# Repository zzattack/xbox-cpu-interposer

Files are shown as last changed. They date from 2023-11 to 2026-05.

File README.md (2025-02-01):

# Repository overview
In this repository schematics, layout and gerber files are shared for the recreation of an interposer PCB allowing upgraded Intel CPUs to be used on the original Xbox console. The designs are made in KiCAD.

# Background
Back in 2003 the Taiwanese company FRIENDTECH came up with methods to upgrade computer systems with faster CPUs, and the original Xbox was among the devices for which they offered an upgrade path. Details of their solution can be found in their patent application https://patents.google.com/patent/US20050282621A1/en.

This _interposer board_ follows the same schematic, minus the poorly functioning clock reduction circuitry, and with the BGA footprint positioned to allow use of the original heatsink mounting holes.

# Contact
I can be contacted at frank@zzattack.org if you're looking to obtain PCBs or CPUs.

# Attribution
This board is a recreation of the original FRIENDTECH design. Revision 1 was a board-level clone of original design through intermediate clones by 'trusty', 'N64freak' and 'Kekule'. Revisions 2 and 3 are re-routed from scratch, inspired by pictures of a similar board with cleaner layout by @gaasedelen, who also kindly assisted in finding issues with early board revisions.

# Installation guide
See [guide](https://github.com/zzattack/xbox-cpu-interposer/blob/main/guide.md).

# Status
Full schematic and PCB are routed. Gerber files are available in the Github releases overview.
Revision 3.2 and onwards should be working correctly.
Prior revisions require PCB modifications and should be avoided.

rev33
rev33_front
rev33_back

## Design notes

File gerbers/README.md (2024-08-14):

# Ordering information

PCB specifications:
 * 6 layer, 49.5x48.6mm
 * Board thickness: 1.6mm
 * Min track size: 5 mil
 * Min clearance: 5 mil
 * Min drill/via size: 0.3mm / 0.4mm
 * Board-to-edge clearance: 0.2mm
 
These specifications can be used to take advantage of the JLCPCB promotional $2 offer for 5 pieces of 6-layer boards.

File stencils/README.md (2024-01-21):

Order as 0.2mm thick stainless steel.



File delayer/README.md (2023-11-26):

# Delayered scans
This folder contains neatly aligned scans of a delayered 'N64freak' interposer.
They were delayered using sanding paper and scanned with a Canon 9000F flatbed scanner.

It is assumed that the 'trusty', 'N64freak' and 'Kekule' clone boards were recreated from similar scans of an original FRIENDTECH board.

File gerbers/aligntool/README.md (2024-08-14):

# Ordering information

PCB specifications:
 * 2 layer, 49.5x48.6mm
 * Board thickness: 1.0mm
 * No specific tight requirements.

This board can be used to accurately determine the position for mounting the actual interposer.
aligntool

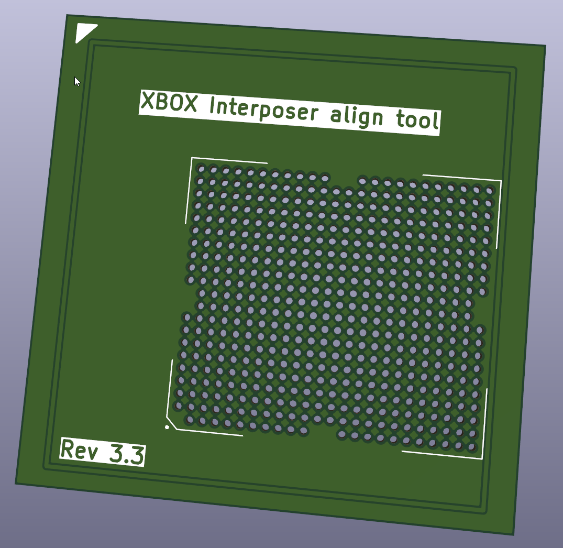
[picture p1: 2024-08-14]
gerbers/aligntool/aligntool.png

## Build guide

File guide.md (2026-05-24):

# XBOX CPU upgrade guide
Applying CPU upgrades to the original Xbox has been done since 2004. Yet, up until recently, resources and information to carry out this procedure have been hard to come by.
This guide aims to gather relevant information, tips and tricks in one place to serve as a reference guide for performing this procedure properly, successfully, and repeatably.
Ideally, even newcomers should succeed on their first try.

Table of Contents
=================
- [XBOX CPU upgrade guide](#xbox-cpu-upgrade-guide)
- [Table of Contents](#table-of-contents)
- [Tools and parts](#tools-and-parts)
- [Motherboard preparations](#motherboard-preparations)
  - [Removal from case](#removal-from-case)
  - [Heatsink removal](#heatsink-removal)
    - [Heatsink bracket removal](#heatsink-bracket-removal)
  - [Thermal paste cleaning](#thermal-paste-cleaning)
  - [Ultrasonic cleaning considerations](#ultrasonic-cleaning-considerations)
  - [Baking](#baking)
- [CPU removal](#cpu-removal)
  - [GPU heat shielding](#gpu-heat-shielding)
  - [CPU lift](#cpu-lift)
    - [Board support](#board-support)
    - [Profile](#profile)
    - [Cooling](#cooling)
- [Interposer mounting](#interposer-mounting)
  - [BGA pads cleaning](#bga-pads-cleaning)
  - [Tenting vias in BGA area](#tenting-vias-in-bga-area)
    - [Why tent the vias?](#why-tent-the-vias)
  - [Positioning the aligntool PCB](#positioning-the-aligntool-pcb)
  - [Interposer preparation](#interposer-preparation)
  - [Soldering the interposer](#soldering-the-interposer)
    - [BGA profile](#bga-profile)
  - [Intermediate checks](#intermediate-checks)
  - [Populating the interposer](#populating-the-interposer)
- [Soldering the CPU](#soldering-the-cpu)
  - [BGA profile](#bga-profile-1)
  - [Testing](#testing)
    - [Troubleshooting](#troubleshooting)
  - [Setting CPU VCORE](#setting-cpu-vcore)
- [CPU/GPU heatsink bracket](#cpugpu-heatsink-bracket)
  - [Capacitor relocation on rev 1.6 motherboard](#capacitor-relocation-on-rev-16-motherboard)
  - [Alternative heatsink mounting solutions](#alternative-heatsink-mounting-solutions)
    - [Thermal glue/adhesive](#thermal-glueadhesive)
    - [Screw mounting posts](#screw-mounting-posts)
  - [Fan recommendation](#fan-recommendation)

<!-- Created by https://github.com/ekalinin/github-markdown-toc -->

# Tools and parts
The most interesting CPUs to place on an original XBOX are part of the Pentium 3 Tualatin family. They have a different PGA-370 footprint compared to the uPGA-495 which is used on the board by default.
We therefore install an adapter in between the board and our intended CPU.

The following parts are needed:
 - [interposer PCB](https://github.com/zzattack/xbox-cpu-interposer/releases/)
 - [components to populate interposer PCB](https://htmlpreview.github.io/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)
 - [aligntool PCB](https://github.com/zzattack/xbox-cpu-interposer/releases/)
 - [socket P370 CPU](https://www.cpu-world.com/sspec/SL/SL6BY.html)
 - [3d-printed heatsink mounting bracket](https://github.com/ACE-AU/OG-Xbox-CPU-GPU-Heatsink-brackets-for-Franks-Interposer)

In order to carry out this procedure you require a fairly well-equipped workshop.
Listed below is the very minimum:
 - BGA station
 - hot-air station
 - (tacky) flux; preferably Amtech
 - soldering iron
 - tweezers
 - desoldering braid/wick
 - UV curable solder mask
 - 0.76mm solder balls
 - assortment of resistors

# Motherboard preparations
Our target for today: a fresh 1.6 original XBOX console. Although differences are minor, this guide will also cover upgrades to non-1.6 revision boards.


This guide will list all the steps taken to upgrade this console with a 1.4 GHz SL6BY CPU.
In general, any socket 370 CPU with 133MHz FSB will function correctly for this mod. The prefererd CPUs to use are SL5XL and SL6BY since those are the only ones operating at 1.4 GHz. Some additional compatibility information can be found [here](https://github.com/N64-Freak/Xbox-CPU-interposer/tree/main/Hardware#choosing-a-processor).

## Removal from case
We start by removing the XBOX motherboard from its case. There's 6x torx-20 screws to remove from the bottom, followed by several torx-10 to get the board out. Several very [detailed writeups](https://www.se7ensins.com/forums/threads/dissassembling-your-xbox-an-in-depth-tutorial.6714/) can be found elsewhere with ease.

## Heatsink removal
First we remove the clamps holding the heatsinks in place. Using a screwdriver the clamps can be unlatched with minor force. I prefer to remove the GPU heatsink from the center of the board, and remove the CPU one from the edge:




 The heatsinks can now be removed. If they feel stuck, do not apply force, since this is likely to strain the BGA balls underneath the chips. Use a hot-air gun for 20-30 seconds at high air speed, or just power on the XBOX for a minute or two, and the heatsink should slide off with ease.
 

 ### Heatsink bracket removal
 The next thing to remove is the heatsink bracket. We will be replacing this with a 3d printed one later on.

 I like to use side cutters to grip underneath the head of the plugs which expand the clips that go through the board. Do not slice the pins too deeply, we will be reusing them later on. As the blade edges slide underneath, you can pull up the clips with relative ease.


Then, from the bottom, regular pliers can be used to push the clips up through the board.


With the bracket separated from the board, take out the clips which held it in place. Take care not to lose these.



The original bracket will not be reused and can be discarded.

## Thermal paste cleaning
The paste that was originally used for these machines isn't very effective. I don't bother removing the paste from the CPU since it gets replaced, but I do like to clean the GPU.
A purpose specific cleaning agent like Arctic Clean is highly effective at removing (any kind of) thermal paste, but generic solutions like isopropyl alcohol or goo-gone work well. If using goo-gone, rinse with alcohol afterwards.


Letting it soak for a minute increases its effectiveness significantly.


Kimtech wipes are industry standard for good reason, but wiping with any lint-free cloth will do.


Cleaned result, good as new.


## Ultrasonic cleaning considerations
Boards were produced since 2000 and thus may have 25 years of gunk collected on them. Depending on the state of the board, one may opt to (ultrasonically) clean it before working on it from a hygiene point of view.
If the board collected primarily dust I will use compressed air to get rid of the worst.
I like to run the board through ultrasonic cleaning only once, so as a rule of thumb: if the board is nasty, clean it before working on it. Otherwise, run it through the ultrasonic after we're done.
Benefit of cleaning afterwards is that all flux residue left behind during our work gets cleaned up perfectly along.

## Baking
Right as you're getting excited to work on your upgrade, I urge you to exert patience. I'm unaware of the history of most boards coming in, and thus prefer to mitigate risk as much as possible.
Boards stored in humid locations may have collected moisture. We'll be heating up the board significantly when replacing its CPU, which may lead to (violent) reactions within the board and/or chips mounted on it.
Particularly the GPU is known to fail if no precautions are taken. Board warp is an additional concern.
My recommendation is (at least) 12h of baking in an oven at about 90°C.

Conveniently, 3d printers with an enclosure typically have sufficient bed area and offer a filament drying option which suits this purpose adequately.


# CPU removal
With the motherboard fully prepared, we're positioned to begin the CPU replacement process.

## GPU heat shielding
The GPU is particularly susceptible to failure if improperly treated. I use aluminum tape to shield it from some of the heat generated during the BGA station cycles. Alternatively, kapton tape or insulating (silicone) thermal pads can be used as well.




## CPU lift
We'll now remove the CPU on the BGA station. The profile I'm using is shown below. It can serve as a starting point, but is by no means a reference.


Each BGA machine differs, and even the climate of the room it is sits in matters significantly, and as such, your profile is specific to your own setup.
A very good BGA machine may be able to accurately control its output to match the temperatures requested in the profile, but for simply removing the CPU, this is not utterly important.


### Board support
To prevent warpage of the motherboard, ensure the board is properly supported along its edges and ideally also in the center. This will prevent board sag. Do not take this lightly!

The machine illustrated below has 6 support pivots, and the bottom heater is positioned against the board, thereby supporting it nicely in the center.


### Profile
What I prefer to do is heat the board using the IR plates, some heat from the bottom, and after a while as the board has heated up, the top heater raises the temperature above the leaded solder melting point.
By probing the edge of the CPU chip with tweezers you can find out when the balls have melted. At this point, stop your profile and quickly lift the chip. No need to strain the board further by letting the profile go on longer than necessary.
20250131_193730 mp4_snapshot_00 03 430

20250131_193746 mp4_snapshot_00 08 864

### Cooling
Let the board cool for ~10 minutes. While the board is warm, it is most prone to warping. Be patient!

# Interposer mounting
With the CPU removed, it's time to continue with the next step in which we solder the interposer onto the XBOX motherboard!

## BGA pads cleaning
First up: cleaning the BGA pads. Apply ample flux, then use a chisel or bevel tip on your iron to go over the BGA area. A lot of solder will stick to your iron. Give the iron a nudge above a waste bin to get rid of most of the excess solder.


About 80% of the solder can be removed this way in mere seconds, which will save a lot on desoldering braid.


Wipe up the remaining solder using desoldering braid. Do **not** exert force on the iron. If your wick won't move, either wait a while (5-10s) for the wick to really heat up, or use a higher temperature on the iron.
Better yet: increase contact surface between iron and the wick. This is why spade-like tips like the one shown below are so effective for this purpose: they are able to really pump heat into the wick, and thereby the pads underneath, allowing for solder to be removed from many pads at once.


Clean up with IPA and kimwipes. Inspect that all pads are nicely flattened.


## Tenting vias in BGA area
The next step is a little tedious and by some considered superfluous. Personally I believe the increased chance of success merits the 10 minutes spent on it.

Using tweezers we apply UV curable solder mask on each of the vias which sit in between the BGA pads in the CPU area.


After curing, the result should look as follows.



### Why tent the vias?
The solder mask on these 25 year old boards is not of incredible quality, so solder easily attaches to the vias if they are not tented as suggested.
Should the interposer move during reflow, it is very likely to cause a solder bridge to develop between a chip BGA pad and PCB via.
This has caused many of my initial attempts to fail, leading to a point where I went to obtain x-ray images of the BGA area. These reveal the bridges formed between via and BGA pad, leading to a failed install.

x2 png 17f4e4579669279c0a5acf65a6f2d83d
 x1 png dea90d838c6f8d1b79eb490e8c339e8e
 unnamed

Since these vias are located in between the 1.27mm pitch of the balls, the alignment needs to be good at about <0.15mm for this not to happen.

Note that at first I did not come up with the techniques where an interposer aligntool PCB is used and the interposer is secured firmly in place. As such, aligning the interposer accurately was *very* difficult.
With the improved technique, we can place the interposer extremely accurately and thereby reduce likelihood of this occurring. As such, it may be fine to omit this step. That said, for the first few upgrades one performs, definitely do not skip it.

## Positioning the aligntool PCB
In order to solder the interposer, we must accurately place it on the BGA pads. The technique described here makes use of an aligntool PCB.
This PCB is manufactured with the exact same dimensions as the actual interposer, and has 0.9mm drill holes going right through where the BGA pads are found on the actual interposer.
This allows as it were to *see through* the interposer, enabling accurate positioning on top of the BGA pads on the XBOX motherboard.

Solder 4 resistors of size 0603 on the underside of the aligntool. This way it is elevated to the same height as the components on the XBOX motherboard, thereby eliminating tilt.


Next align it so that the holes cover the centers of the BGA pads, and then tape it in place.


You may have to move capacitor C1D4 down slightly for the aligntool to position properly. With rev 3.3 interposers this is not strictly necessary, but board variations might dictate otherwise.


We'll now solder some (bulky) SMD capacitors along the edges of the aligntool PCB. Either attach them to surrounding passives, or scrape away some solder mask to reveal some copper to which the capacitors can attach with solder.


Suggested locations for the 1.6 revision are shown below.


For other revisions, capacitor locations as used in the following picture work well.


> Note: It's best not to completely box in the aligntool, but allow for some very minor play. Manufacturing tolerances may result in slightly different outlines between aligntool and interposer. During soldering, the interposer will settle in place correctly.

## Interposer preparation
Specifically of note: tack balls using thin layer of flux + very low air speed. Once attached, use (much) more flux and high air speed. Make balls look shiny. Clean with IPA.
reballed

## Soldering the interposer
Remove the tape from the aligntool and verify that it placing it in between the capacitors along its edge positions the PCB properly. If so, it's time to solder the interposer.
Apply a small layer of flux on the BGA pads and use a brush or your finger (wear gloves, e.g. nitrile) to distribute a very thin layer. Note that more flux is not beneficial: it increases likelihood for balls to travel during reflow.



Then place the interposer and head over to the BGA station.


### BGA profile
Shown below is the BGA machine profile I use for the interposer. Again, this may not apply directly to your situation. Adapt as necessary.


The main idea here is to have the board temperature attempt to follow the recommended reflow profile for the (Amtech) flux that I am using. Additionally, it contains some controlled cooldown (4th through 6th column of the profile).
firefox_tVtUtnWohH

After the profile finishes, allow the board to cool down for about 10 minutes before continuing to work on it.

## Intermediate checks
At this point clearly the XBOX cannot boot, but there are a few things we should verify to ensure we're good to carry on.
Briefly remove the GPU heat shielding tape from both sides of the board before performing these measurements.

On the interposer, measure the following using a digital multimeter:
 - VCORE --> reading should start at ~50 ohms, then continues to rise indefinitely
 - VREF  --> ~75 ohms stable
 - VTT   --> ~50 ohms stable
pcbnew_oaYOb1aO3B

If any of these read differently, the interposer is incorrectly aligned or a bridge has formed underneath it. It is then **pointless to continue**.
Remove the interposer and start fresh. In this case I always recommend return to stock state, with the original CPU.

For non rev-1.6 boards, the next check is for the voltage rail powering the MCPX and XGPU:
 - VGPU: ~20 ohms, slowly rising -- measures 1.75V when powered on.
Must be AT LEAST 2.5 ohms. If it reads <1 ohm the board has warped and a bridge has formed under the XGPU, or the XGPU has died from the heat. In most cases the board cannot be resurrected without transplanting or reballing the XGPU.


Finally, if these checks pass, turn on the XBOX. just the AV cord, PSU and front panel need to be connected.

We expect the XBOX to FRAG. Other outcomes:
 - If the XBOX does not turn on: probably a short that needs to be resolved. Remove interposer and start over.
 - If front LED blinks orange and fans turn on at 100%: likely a bridge on some of the address lines. Remove interposer and start over.

Put the aluminum tape back before continuing with the next steps.

## Populating the interposer
Unless you obtained a prepopulated interposer, solder the components from the [BOM](https://htmlpreview.github.io/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) onto the interposer now.
These are simple resistors and capacitors and should form no challenge if you're tackling a procedure like this.

# Soldering the CPU
We've arrived at the final step of the procedure: soldering the actual CPU.

For some background info: the CPU sits on top of the interposer. While soldering the CPU, we do not wish to reflow the BGA balls which attach the interposer to the XBOX motherboard. To achieve this, we use a *Bismuth* soldering paste with lower melting temperature (138°C) than the leaded balls (183°C).
I personally like to use TS391LT from CHIPQUICK for this. The purple needle head works nicely for distributing a correct amount of paste pneumatically, but dispensing by hand is completely viable too.


Pneumatic dispenser with foot pedal and timed bursts allows for placing the 370 solder paste blobs in about 5 minutes.



Now place your CPU centered in the blobs. Try to be as accurate as possible when initially setting it down. If adjustments are needed, lift the CPU slightly instead of shoving while the pins still make contact with the interposer.

Make sure alignment is good before placing the board onto your BGA machine.


## BGA profile
Starting point for the BGA profile for the CPU with Bi57 paste:


Again, adapt to your situation. When the paste melts, the effect of the paste *creeping* up onto the CPU pins is quite pleasing to watch.

I like to use a 60x60mm nozzle which is able to get all the pins to melting temperature roughly at the same time.


Again, wait about 10 minutes after the profile completes before handling the board so as to not unnecessarily stress it or induce potential warping.

## Testing
At this point, the XBOX should boot! Inspect the pins to ensure all paste has melted and no bridges have formed. Remove the GPU heat shielding tape once more.


If so, power it on and keep your fingers crossed. If you get a boot logo, turn off the XBOX. The CPU is still operating at 1.70V but it's intended for only 1.45V, so we'll address that next.


If the XBOX boots, congratulations, you have performed potentially one of the toughest console mods out there.

### Troubleshooting
If it does not boot, unfortunately, not a lot of diagnosis other than what was mentioned in the _Intermediate checks_ section is possible. A thermal cam could reveal potential shorts.
It's also quite possible that some of the balls simply did not make proper contact. Do not give up. Most people needed many attempts (>10 for some!) to record their first success.
Some general tips:
 - Work cleanly. Use isopropyl alcohol after every step involving flux.
 - Take your time, work patiently. This is a large effort and is often too much work to run in one sitting.
 - Refer to this guide constantly. Do not skip steps. Double/triple check your work.
 - If anything feels like it could be improved, do so right away. That's always less work than restarting from scratch.
 - Babysit the BGA profiles at first:
   - Watch closely for board warp.
   - Use a temperature probe taped to the side of the original CPU to get a feel for board temperature.
   - Adjust the profiles if they heat up too much, too fast, or not enough.

Diagram below shows expected voltage readings when console is powered on.
** For 009 boards (rev 1.0-1.2)
009-rear
009-front

** For 012 boards (rev 1.3-1.4)
TODO

** For 121 boards (rev 1.6)
Inner
(picture courtesy of @RedHerring32)

## Setting CPU VCORE
The original CPU ran at 1.70V while the Tualatin replacement is intended to run at 1.45V. You can usually go a bit lower even, which helps to generate less heat, at the cost of potential stability.
This can only be found out by trial and error; some run fine at 1.35V while others won't allow to go below 1.40V at all. This is evidenced by the console hanging unexpectedly during gameplay or even during the flutter bootup animation.
The [ACE-AU github](https://github.com/ACE-AU/OGX-PIII-CPU-VCORE-SETTINGS) contains detailed information for each of the board revisions.

# CPU/GPU heatsink bracket
Due to the form factor difference, we cannot secure the original heatsinks to the CPU and GPU using the original bracket. Instead we use a 3d printed modified version which allows us to clamp the original heatsinks in place.
https://github.com/ACE-AU/OG-Xbox-CPU-GPU-Heatsink-brackets-for-Franks-Interposer
Alternatively, eBay seller [computerbooter](https://www.ebay.com/str/computerbooter916) sells these brackets cheaply.

To mount them, reuse the 5 clips and push pins from the original bracket. The one near pin 1 of the CPU needs to be clipped to fit, which is easily done using side cutters.


The original heatsink is slightly too high to sit under the standard HDD tray. You must trim at least 5.5mm off the top of the fins to make it fit.

## Capacitor relocation on rev 1.6 motherboard
On revision 1.6 motherboards, one electrolyic capacitor which sits between the fan and heatsink bracket needs to be moved slightly. After desoldering it, I mount the bracket and lay the capacitor flat on its side before attaching the snipped-off legs from an LED or another capacitor to its anode/cathode. Do pay attention to its marking since these are polarized!


## Alternative heatsink mounting solutions
If acquiring a 3d-printed bracket is infeasible then several alternative solutions can be used. They are briefly summarized below:

### Thermal glue/adhesive
This method is very easy to apply: simply apply thermal glue to the CPU, then place the heatsink on top. This forms a permanent bond which probably destroys the install if you attempt to ever remove it. This way you do not require any kind of mounting bracket, clamping solution, or screw holes solution.
You could then use a smaller heatsink such as this [low-profile one](https://nl.rs-online.com/web/p/heatsinks/1898628) from Fischer Elektronik, which fits underneath the HDD tray. It is easily cut up into 3 parts and therefore relatively cheap.


Although thermal glue has way worse conductive properties than thermal paste, decent results can be obtained. [EC360](https://www.coolsierra.com/collections/thermal-adhesive/products/ec360-glue) in particular has given me passable results in the past.

### Screw mounting posts
Another option involves cutting the fins on the heatsink to make room for screw holes. You can use the original bracket as a template for positioning the screw holes. This involves a fair bit of work and the combination of screws, optional washers and spacer stud needs to be just right. It does allow for an easily removed heatsink, and thermal properties are quite good if you mount in 3 opposing corners.
> Note: it's very easy to over-tighten screws using this solution. This might cause strain on the BGA balls and even break the installation if performed incorrectly!




## Fan recommendation
The upgraded CPUs use a lot more power than the original one, up to 30-35W, whereas the original one was closer to 25W. Poor heatsink solutions will cause the CPU to run quite hot. It's important that the temperature remains (well) below their maximum safe operating temperature of 85°C.
Many have opted to replace the somewhat noisy stock fan with a lower RPM one such as 50mm Noctuas, but this is ill advised. The silent operation is mostly achieved through lower fan speed and thereby lower airflow, but these CPUs require adequate cooling. My recommendation is to use good thermal paste, properly applied, along with the stock fan operating at >70% fan speed. This should keep temperatures under 60°C even during prolonged use.

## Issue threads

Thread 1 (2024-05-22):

unable to identify RN1 required component

crijopoga, 2024-05-22:
i was looking for required parts using the specified BOM file but i was unable to find any "R_Network04". any more specific data about it please?

j44dge, 2024-05-23:
I'm also wondering about this.

j44dge, 2024-05-23:
Also just to add, is there any guide for this? Do people need to modify any resistors on the OG Xbox board for V-Core voltage etc??

AR1972, 2024-05-25:
the components are the same as the old interposer
https://github.com/N64-Freak/Xbox-CPU-interposer/tree/main/Hardware

vcore does need to be changed
https://github.com/ACE-AU/OGX-PIII-CPU-VCORE-SETTINGS/blob/main/Xbox%20V1.2-1.4%20VCORE%20Mod.pdf

zzattack, 2024-08-14:
No longer relevant, it's split into 4 separate 0603 resistors of 1k.

Closed 2024-08-14.

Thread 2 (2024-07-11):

Help needed to add gerber files to pcb manufacturer

Sopor, 2024-07-11:
I'm trying to add these gerber files to pcb manufacturer i have found online, but i haven't manage to get it right 😥

I get the interposer and the aligntool correct (I think), but how do i add the stencils?

When i add the stencils i can't select stainless steel and it doesn't look as the right size.

Any help is appreciated 😍

zzattack, 2024-08-14:
Cannot help with this, best to work it out with your manufacturer

Closed 2024-08-14.

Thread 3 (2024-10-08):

Revision v3.3 not able to be processed by JLC PCB due to trace clearances

RetroModzUK, 2024-10-08:
I have tried to have revision v3.3 pcb's produced via JLC PCB

Revision v3.3 not able to be processed by JLC PCB due to trace clearances.

message from JLC PCB web chat

The clearance of trace are too close which is out of our capabilities
Could you please enlarge them to at least 0.09m

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

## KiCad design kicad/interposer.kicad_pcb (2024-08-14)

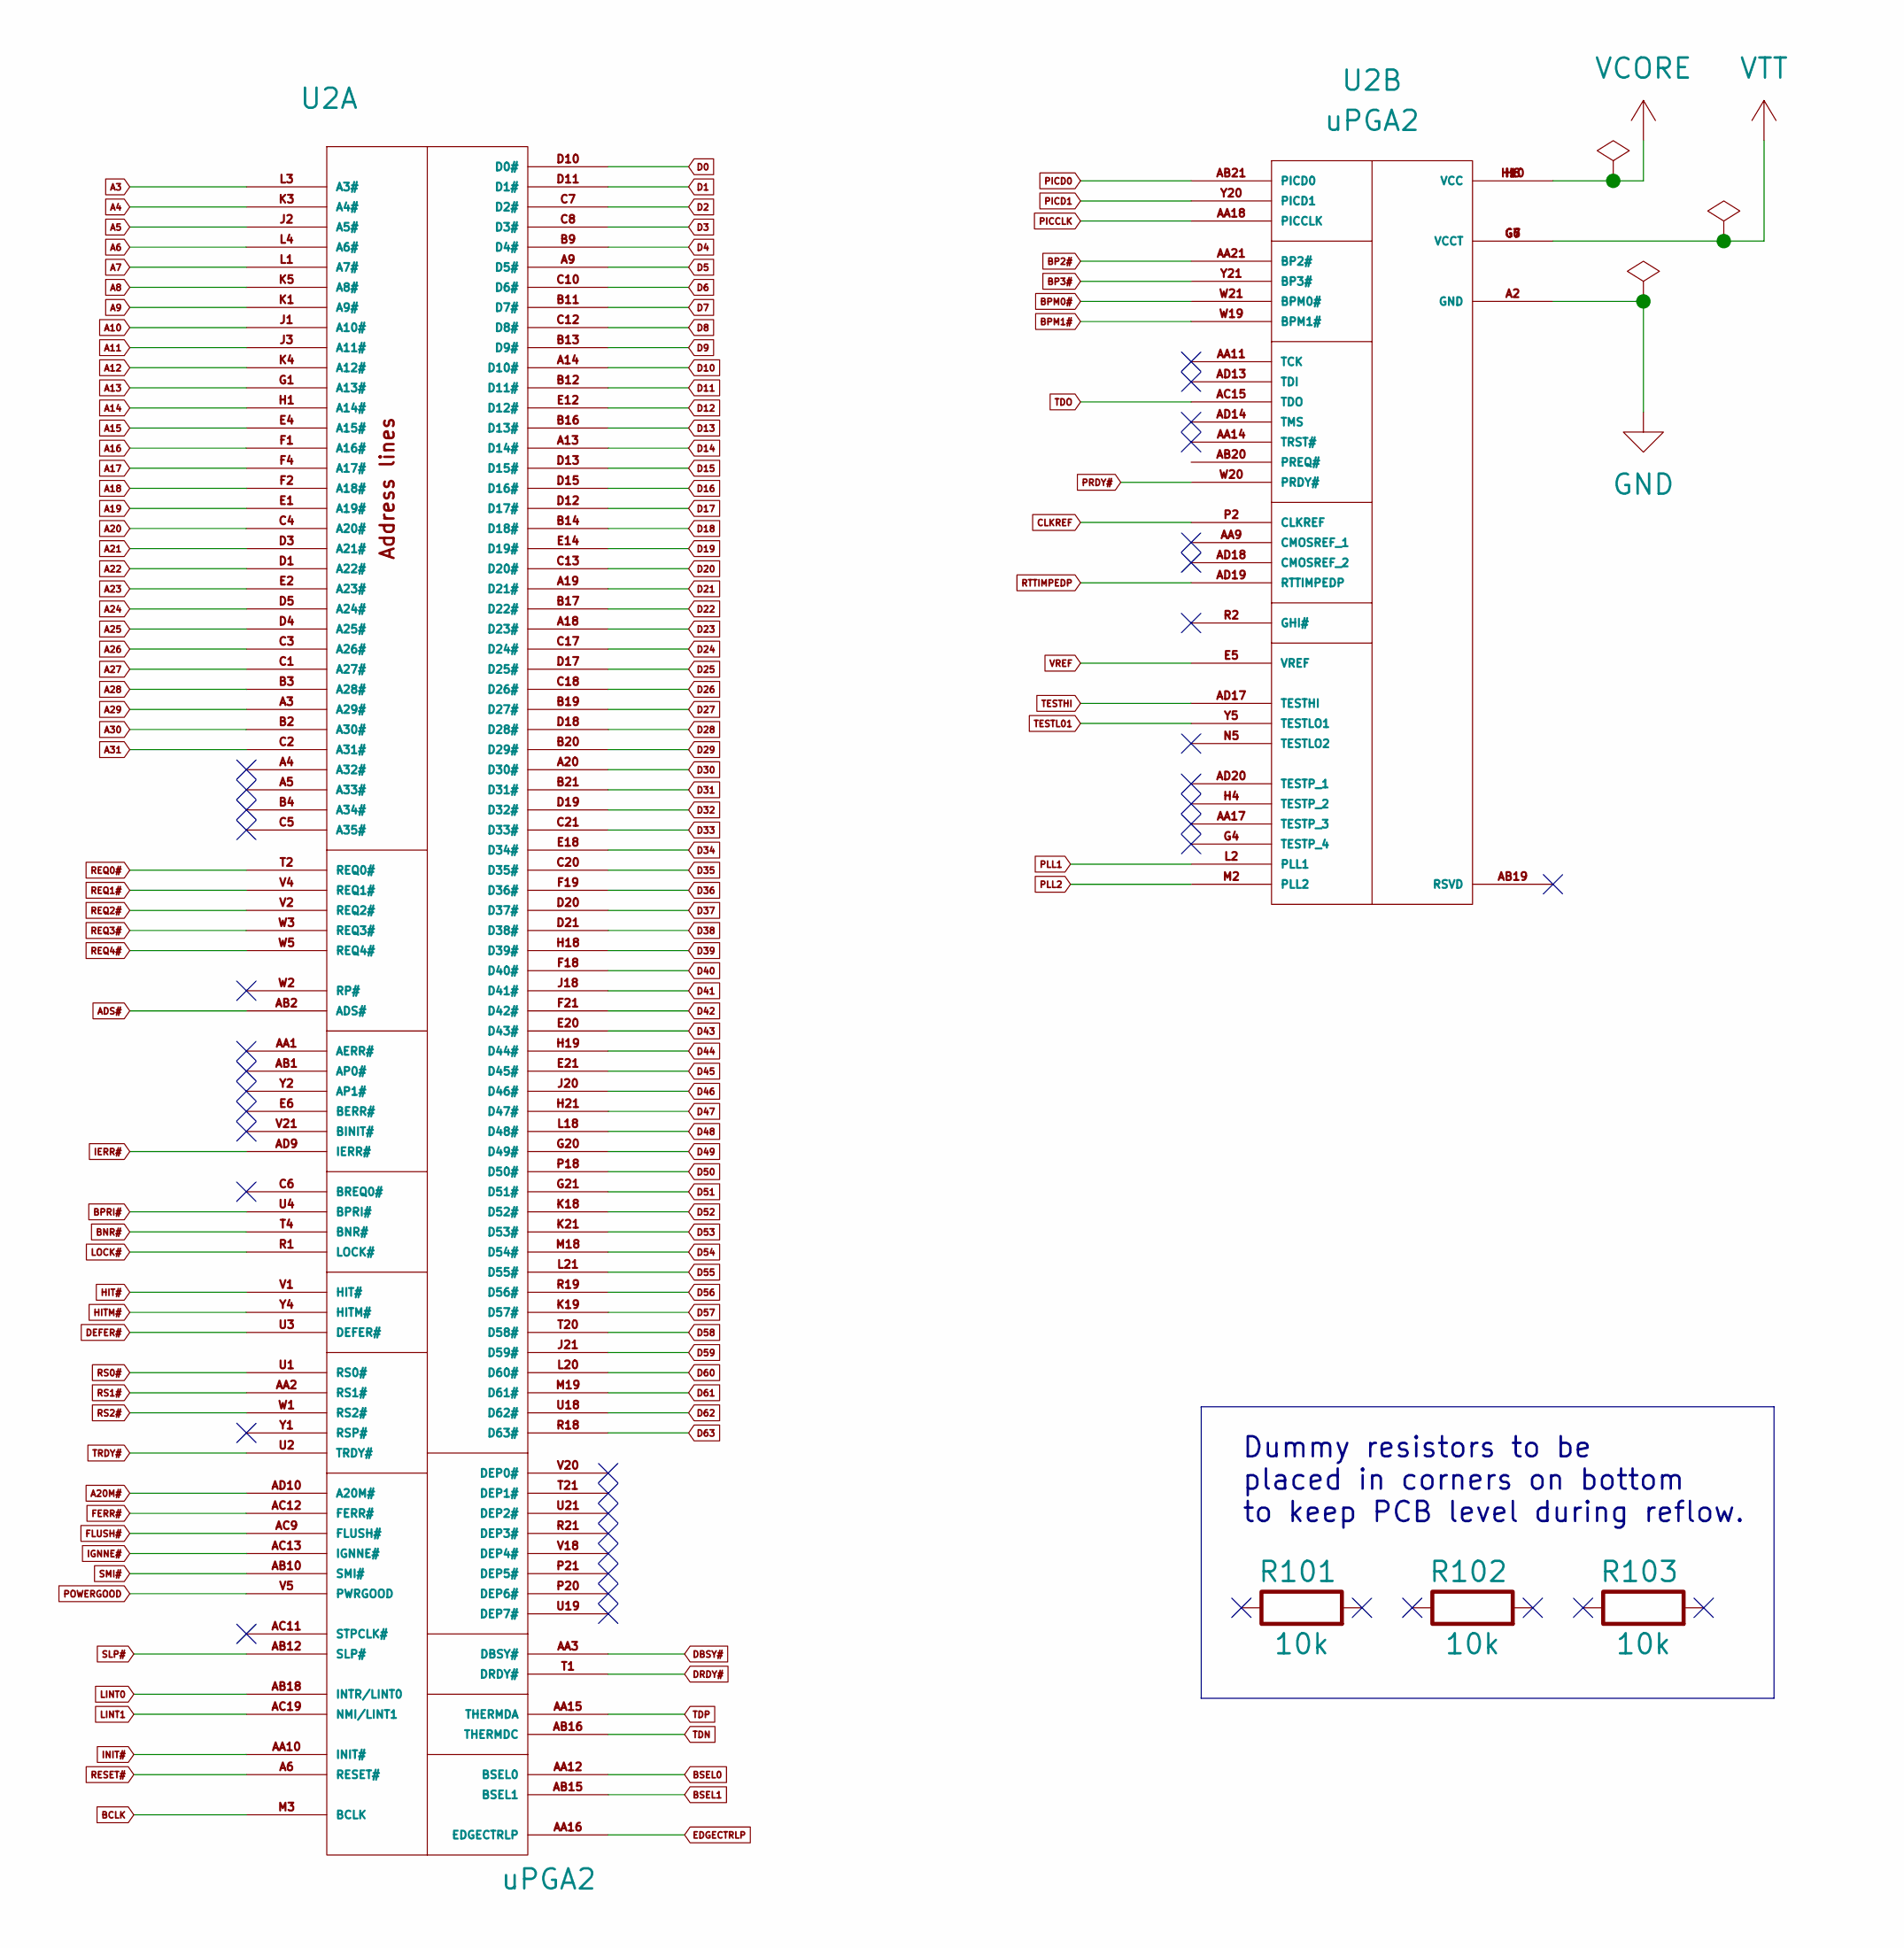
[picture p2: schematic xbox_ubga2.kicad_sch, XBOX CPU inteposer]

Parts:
R101, R102, R103: 10k; R_0603_1608Metric
U2: uPGA2; uBGA495-mirrored

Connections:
A3: U2.L3 (A3#); also elsewhere on the board
A4: U2.K3 (A4#); also elsewhere on the board
A5: U2.J2 (A5#); also elsewhere on the board
A6: U2.L4 (A6#); also elsewhere on the board
A7: U2.L1 (A7#); also elsewhere on the board
A8: U2.K5 (A8#); also elsewhere on the board
A9: U2.K1 (A9#); also elsewhere on the board
A10: U2.J1 (A10#); also elsewhere on the board
A11: U2.J3 (A11#); also elsewhere on the board
A12: U2.K4 (A12#); also elsewhere on the board
A13: U2.G1 (A13#); also elsewhere on the board
A14: U2.H1 (A14#); also elsewhere on the board
A15: U2.E4 (A15#); also elsewhere on the board
A16: U2.F1 (A16#); also elsewhere on the board
A17: U2.F4 (A17#); also elsewhere on the board
A18: U2.F2 (A18#); also elsewhere on the board
A19: U2.E1 (A19#); also elsewhere on the board
A20: U2.C4 (A20#); also elsewhere on the board
A20M#: U2.AD10 (A20M#); also elsewhere on the board
A21: U2.D3 (A21#); also elsewhere on the board
A22: U2.D1 (A22#); also elsewhere on the board
A23: U2.E2 (A23#); also elsewhere on the board
A24: U2.D5 (A24#); also elsewhere on the board
A25: U2.D4 (A25#); also elsewhere on the board
A26: U2.C3 (A26#); also elsewhere on the board
A27: U2.C1 (A27#); also elsewhere on the board
A28: U2.B3 (A28#); also elsewhere on the board
A29: U2.A3 (A29#); also elsewhere on the board
A30: U2.B2 (A30#); also elsewhere on the board
A31: U2.C2 (A31#); also elsewhere on the board
ADS#: U2.AB2 (ADS#); also elsewhere on the board
BCLK: U2.M3 (BCLK); also elsewhere on the board
BNR#: U2.T4 (BNR#); also elsewhere on the board
BP2#: U2.AA21 (BP2#); also elsewhere on the board
BP3#: U2.Y21 (BP3#); also elsewhere on the board
BPM0#: U2.W21 (BPM0#); also elsewhere on the board
BPM1#: U2.W19 (BPM1#); also elsewhere on the board
BPRI#: U2.U4 (BPRI#); also elsewhere on the board
BSEL0: U2.AA12 (BSEL0); also elsewhere on the board
BSEL1: U2.AB15 (BSEL1); also elsewhere on the board
CLKREF: U2.P2 (CLKREF); also elsewhere on the board
D0: U2.D10 (D0#); also elsewhere on the board
D1: U2.D11 (D1#); also elsewhere on the board
D2: U2.C7 (D2#); also elsewhere on the board
D3: U2.C8 (D3#); also elsewhere on the board
D4: U2.B9 (D4#); also elsewhere on the board
D5: U2.A9 (D5#); also elsewhere on the board
D6: U2.C10 (D6#); also elsewhere on the board
D7: U2.B11 (D7#); also elsewhere on the board
D8: U2.C12 (D8#); also elsewhere on the board
D9: U2.B13 (D9#); also elsewhere on the board
D10: U2.A14 (D10#); also elsewhere on the board
D11: U2.B12 (D11#); also elsewhere on the board
D12: U2.E12 (D12#); also elsewhere on the board
D13: U2.B16 (D13#); also elsewhere on the board
D14: U2.A13 (D14#); also elsewhere on the board
D15: U2.D13 (D15#); also elsewhere on the board
D16: U2.D15 (D16#); also elsewhere on the board
D17: U2.D12 (D17#); also elsewhere on the board
D18: U2.B14 (D18#); also elsewhere on the board
D19: U2.E14 (D19#); also elsewhere on the board
D20: U2.C13 (D20#); also elsewhere on the board
D21: U2.A19 (D21#); also elsewhere on the board
D22: U2.B17 (D22#); also elsewhere on the board
D23: U2.A18 (D23#); also elsewhere on the board
D24: U2.C17 (D24#); also elsewhere on the board
D25: U2.D17 (D25#); also elsewhere on the board
D26: U2.C18 (D26#); also elsewhere on the board
D27: U2.B19 (D27#); also elsewhere on the board
D28: U2.D18 (D28#); also elsewhere on the board
D29: U2.B20 (D29#); also elsewhere on the board
D30: U2.A20 (D30#); also elsewhere on the board
D31: U2.B21 (D31#); also elsewhere on the board
D32: U2.D19 (D32#); also elsewhere on the board
D33: U2.C21 (D33#); also elsewhere on the board
D34: U2.E18 (D34#); also elsewhere on the board
D35: U2.C20 (D35#); also elsewhere on the board
D36: U2.F19 (D36#); also elsewhere on the board
D37: U2.D20 (D37#); also elsewhere on the board
D38: U2.D21 (D38#); also elsewhere on the board
D39: U2.H18 (D39#); also elsewhere on the board
D40: U2.F18 (D40#); also elsewhere on the board
D41: U2.J18 (D41#); also elsewhere on the board
D42: U2.F21 (D42#); also elsewhere on the board
D43: U2.E20 (D43#); also elsewhere on the board
D44: U2.H19 (D44#); also elsewhere on the board
D45: U2.E21 (D45#); also elsewhere on the board
D46: U2.J20 (D46#); also elsewhere on the board
D47: U2.H21 (D47#); also elsewhere on the board
D48: U2.L18 (D48#); also elsewhere on the board
D49: U2.G20 (D49#); also elsewhere on the board
D50: U2.P18 (D50#); also elsewhere on the board
D51: U2.G21 (D51#); also elsewhere on the board
D52: U2.K18 (D52#); also elsewhere on the board
D53: U2.K21 (D53#); also elsewhere on the board
D54: U2.M18 (D54#); also elsewhere on the board
D55: U2.L21 (D55#); also elsewhere on the board
D56: U2.R19 (D56#); also elsewhere on the board
D57: U2.K19 (D57#); also elsewhere on the board
D58: U2.T20 (D58#); also elsewhere on the board
D59: U2.J21 (D59#); also elsewhere on the board
D60: U2.L20 (D60#); also elsewhere on the board
D61: U2.M19 (D61#); also elsewhere on the board
D62: U2.U18 (D62#); also elsewhere on the board
D63: U2.R18 (D63#); also elsewhere on the board
DBSY#: U2.AA3 (DBSY#); also elsewhere on the board
DEFER#: U2.U3 (DEFER#); also elsewhere on the board
DRDY#: U2.T1 (DRDY#); also elsewhere on the board
EDGECTRLP: U2.AA16 (EDGECTRLP); also elsewhere on the board
FERR#: U2.AC12 (FERR#); also elsewhere on the board
FLUSH#: U2.AC9 (FLUSH#); also elsewhere on the board
GND: U2.A2 (GND), U2.A7 (GND), U2.A8 (GND), U2.A12 (GND), U2.A21 (GND), U2.AA4 (GND), U2.AA13 (GND), U2.AA20 (GND), U2.AB3 (GND), U2.AB5 (GND), U2.AB9 (GND), U2.AB11 (GND), U2.AB13 (GND), U2.AB14 (GND), U2.AB17 (GND), U2.AC1 (GND), U2.AC2 (GND), U2.AC5 (GND), U2.AC10 (GND), U2.AC14 (GND), U2.AC16 (GND), U2.AC18 (GND), U2.AC21 (GND), U2.AD1 (GND), U2.AD5 (GND), U2.AD16 (GND), U2.AD21 (GND), U2.B1 (GND), U2.B5 (GND), U2.B6 (GND), U2.B7 (GND), U2.B8 (GND), U2.B10 (GND), U2.B15 (GND), U2.B18 (GND), U2.C9 (GND), U2.C11 (GND), U2.C15 (GND), U2.C16 (GND), U2.C19 (GND), U2.D2 (GND), U2.D6 (GND), U2.D7 (GND), U2.D9 (GND), U2.E3 (GND), U2.E7 (GND), U2.E8 (GND), U2.E9 (GND), U2.E10 (GND), U2.E11 (GND), U2.E13 (GND), U2.E19 (GND), U2.F3 (GND), U2.F6 (GND), U2.F7 (GND), U2.F8 (GND), U2.F9 (GND), U2.F10 (GND), U2.F11 (GND), U2.F12 (GND), U2.F13 (GND), U2.F14 (GND), U2.F15 (GND), U2.F16 (GND), U2.F20 (GND), U2.G3 (GND), U2.G19 (GND), U2.H2 (GND), U2.H7 (GND), U2.H9 (GND), U2.H11 (GND), U2.H13 (GND), U2.H15 (GND), U2.H20 (GND), U2.J4 (GND), U2.J8 (GND), U2.J10 (GND), U2.J12 (GND), U2.J14 (GND), U2.J16 (GND), U2.J19 (GND), U2.K2 (GND), U2.K7 (GND), U2.K9 (GND), U2.K11 (GND), U2.K13 (GND), U2.K15 (GND), U2.K20 (GND), U2.L5 (GND), U2.L8 (GND), U2.L10 (GND), U2.L12 (GND), U2.L14 (GND), U2.L16 (GND), U2.L19 (GND), U2.M7 (GND), U2.M9 (GND), U2.M11 (GND), U2.M13 (GND), U2.M15 (GND), U2.M20 (GND), U2.N2 (GND), U2.N3 (GND), U2.N4 (GND), U2.N8 (GND), U2.N10 (GND), U2.N12 (GND), U2.N14 (GND), U2.N16 (GND), U2.N18 (GND), U2.N19 (GND), U2.N20 (GND), U2.P5 (GND), U2.P7 (GND), U2.P9 (GND), U2.P11 (GND), U2.P13 (GND), U2.P15 (GND), U2.P19 (GND), U2.R3 (GND), U2.R4 (GND), U2.R5 (GND), U2.R8 (GND), U2.R10 (GND), U2.R12 (GND), U2.R14 (GND), U2.R16 (GND), U2.R20 (GND), U2.T3 (GND), U2.T5 (GND), U2.T7 (GND), U2.T9 (GND), U2.T11 (GND), U2.T13 (GND), U2.T15 (GND), U2.T18 (GND), U2.T19 (GND), U2.U8 (GND), U2.U10 (GND), U2.U12 (GND), U2.U14 (GND), U2.U16 (GND), U2.U20 (GND), U2.V3 (GND), U2.V19 (GND), U2.W4 (GND), U2.W18 (GND), U2.Y3 (GND), U2.Y9 (GND), U2.Y10 (GND), U2.Y11 (GND), U2.Y12 (GND), U2.Y13 (GND), U2.Y14 (GND), U2.Y15 (GND), U2.Y16 (GND), U2.Y19 (GND); also elsewhere on the board
HIT#: U2.V1 (HIT#); also elsewhere on the board
HITM#: U2.Y4 (HITM#); also elsewhere on the board
IERR#: U2.AD9 (IERR#); also elsewhere on the board
IGNNE#: U2.AC13 (IGNNE#); also elsewhere on the board
INIT#: U2.AA10 (INIT#); also elsewhere on the board
LINT0: U2.AB18 (INTR/LINT0); also elsewhere on the board
LINT1: U2.AC19 (NMI/LINT1); also elsewhere on the board
LOCK#: U2.R1 (LOCK#); also elsewhere on the board
PICCLK: U2.AA18 (PICCLK); also elsewhere on the board
PICD0: U2.AB21 (PICD0); also elsewhere on the board
PICD1: U2.Y20 (PICD1); also elsewhere on the board
PLL1: U2.L2 (PLL1); also elsewhere on the board
PLL2: U2.M2 (PLL2); also elsewhere on the board
POWERGOOD: U2.V5 (PWRGOOD); also elsewhere on the board
PRDY#: U2.W20 (PRDY#); also elsewhere on the board
REQ0#: U2.T2 (REQ0#); also elsewhere on the board
REQ1#: U2.V4 (REQ1#); also elsewhere on the board
REQ2#: U2.V2 (REQ2#); also elsewhere on the board
REQ3#: U2.W3 (REQ3#); also elsewhere on the board
REQ4#: U2.W5 (REQ4#); also elsewhere on the board
RESET#: U2.A6 (RESET#); also elsewhere on the board
RS0#: U2.U1 (RS0#); also elsewhere on the board
RS1#: U2.AA2 (RS1#); also elsewhere on the board
RS2#: U2.W1 (RS2#); also elsewhere on the board
RTTIMPEDP: U2.AD19 (RTTIMPEDP); also elsewhere on the board
SLP#: U2.AB12 (SLP#); also elsewhere on the board
SMI#: U2.AB10 (SMI#); also elsewhere on the board
TDN: U2.AB16 (THERMDC); also elsewhere on the board
TDO: U2.AC15 (TDO); also elsewhere on the board
TDP: U2.AA15 (THERMDA); also elsewhere on the board
TESTHI: U2.AD17 (TESTHI); also elsewhere on the board
TESTL01: U2.Y5 (TESTLO1); also elsewhere on the board
TRDY#: U2.U2 (TRDY#); also elsewhere on the board
VCORE: U2.H8 (VCC), U2.H10 (VCC), U2.H12 (VCC), U2.H14 (VCC), U2.H16 (VCC), U2.J7 (VCC), U2.J9 (VCC), U2.J11 (VCC), U2.J13 (VCC), U2.J15 (VCC), U2.K8 (VCC), U2.K10 (VCC), U2.K12 (VCC), U2.K14 (VCC), U2.K16 (VCC), U2.L7 (VCC), U2.L9 (VCC), U2.L11 (VCC), U2.L13 (VCC), U2.L15 (VCC), U2.M8 (VCC), U2.M10 (VCC), U2.M12 (VCC), U2.M14 (VCC), U2.M16 (VCC), U2.N7 (VCC), U2.N9 (VCC), U2.N11 (VCC), U2.N13 (VCC), U2.N15 (VCC), U2.P1 (VCC), U2.P8 (VCC), U2.P10 (VCC), U2.P12 (VCC), U2.P14 (VCC), U2.P16 (VCC), U2.R7 (VCC), U2.R9 (VCC), U2.R11 (VCC), U2.R13 (VCC), U2.R15 (VCC), U2.T8 (VCC), U2.T10 (VCC), U2.T12 (VCC), U2.T14 (VCC), U2.T16 (VCC), U2.U7 (VCC), U2.U9 (VCC), U2.U11 (VCC), U2.U13 (VCC), U2.U15 (VCC); also elsewhere on the board
VREF: U2.E5 (VREF), U2.E16 (VREF), U2.E17 (VREF), U2.F5 (VREF), U2.F17 (VREF), U2.U5 (VREF), U2.Y17 (VREF), U2.Y18 (VREF); also elsewhere on the board
VTT: U2.AA6 (VCCT), U2.AA7 (VCCT), U2.AA8 (VCCT), U2.AB6 (VCCT), U2.AB7 (VCCT), U2.AB8 (VCCT), U2.AC6 (VCCT), U2.AC7 (VCCT), U2.AC8 (VCCT), U2.AD6 (VCCT), U2.AD7 (VCCT), U2.AD8 (VCCT), U2.G6 (VCCT), U2.G7 (VCCT), U2.G8 (VCCT), U2.G9 (VCCT), U2.G10 (VCCT), U2.G11 (VCCT), U2.G12 (VCCT), U2.G13 (VCCT), U2.G14 (VCCT), U2.G15 (VCCT), U2.G16 (VCCT), U2.G17 (VCCT), U2.H6 (VCCT), U2.H17 (VCCT), U2.J6 (VCCT), U2.J17 (VCCT), U2.K6 (VCCT), U2.K17 (VCCT), U2.L6 (VCCT), U2.L17 (VCCT), U2.M6 (VCCT), U2.M17 (VCCT), U2.N6 (VCCT), U2.N17 (VCCT), U2.P6 (VCCT), U2.P17 (VCCT), U2.R6 (VCCT), U2.R17 (VCCT), U2.T6 (VCCT), U2.T17 (VCCT), U2.U6 (VCCT), U2.U17 (VCCT), U2.V6 (VCCT), U2.V7 (VCCT), U2.V8 (VCCT), U2.V9 (VCCT), U2.V10 (VCCT), U2.V11 (VCCT), U2.V12 (VCCT), U2.V13 (VCCT), U2.V14 (VCCT), U2.V15 (VCCT), U2.V16 (VCCT), U2.V17 (VCCT), U2.W6 (VCCT), U2.W7 (VCCT), U2.W8 (VCCT), U2.W9 (VCCT), U2.W10 (VCCT), U2.W11 (VCCT), U2.W12 (VCCT), U2.W13 (VCCT), U2.W14 (VCCT), U2.W15 (VCCT), U2.W16 (VCCT), U2.W17 (VCCT), U2.Y6 (VCCT), U2.Y7 (VCCT), U2.Y8 (VCCT); also elsewhere on the board

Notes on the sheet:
Dummy resistors to be placed in corners on bottom to keep PCB level during reflow.

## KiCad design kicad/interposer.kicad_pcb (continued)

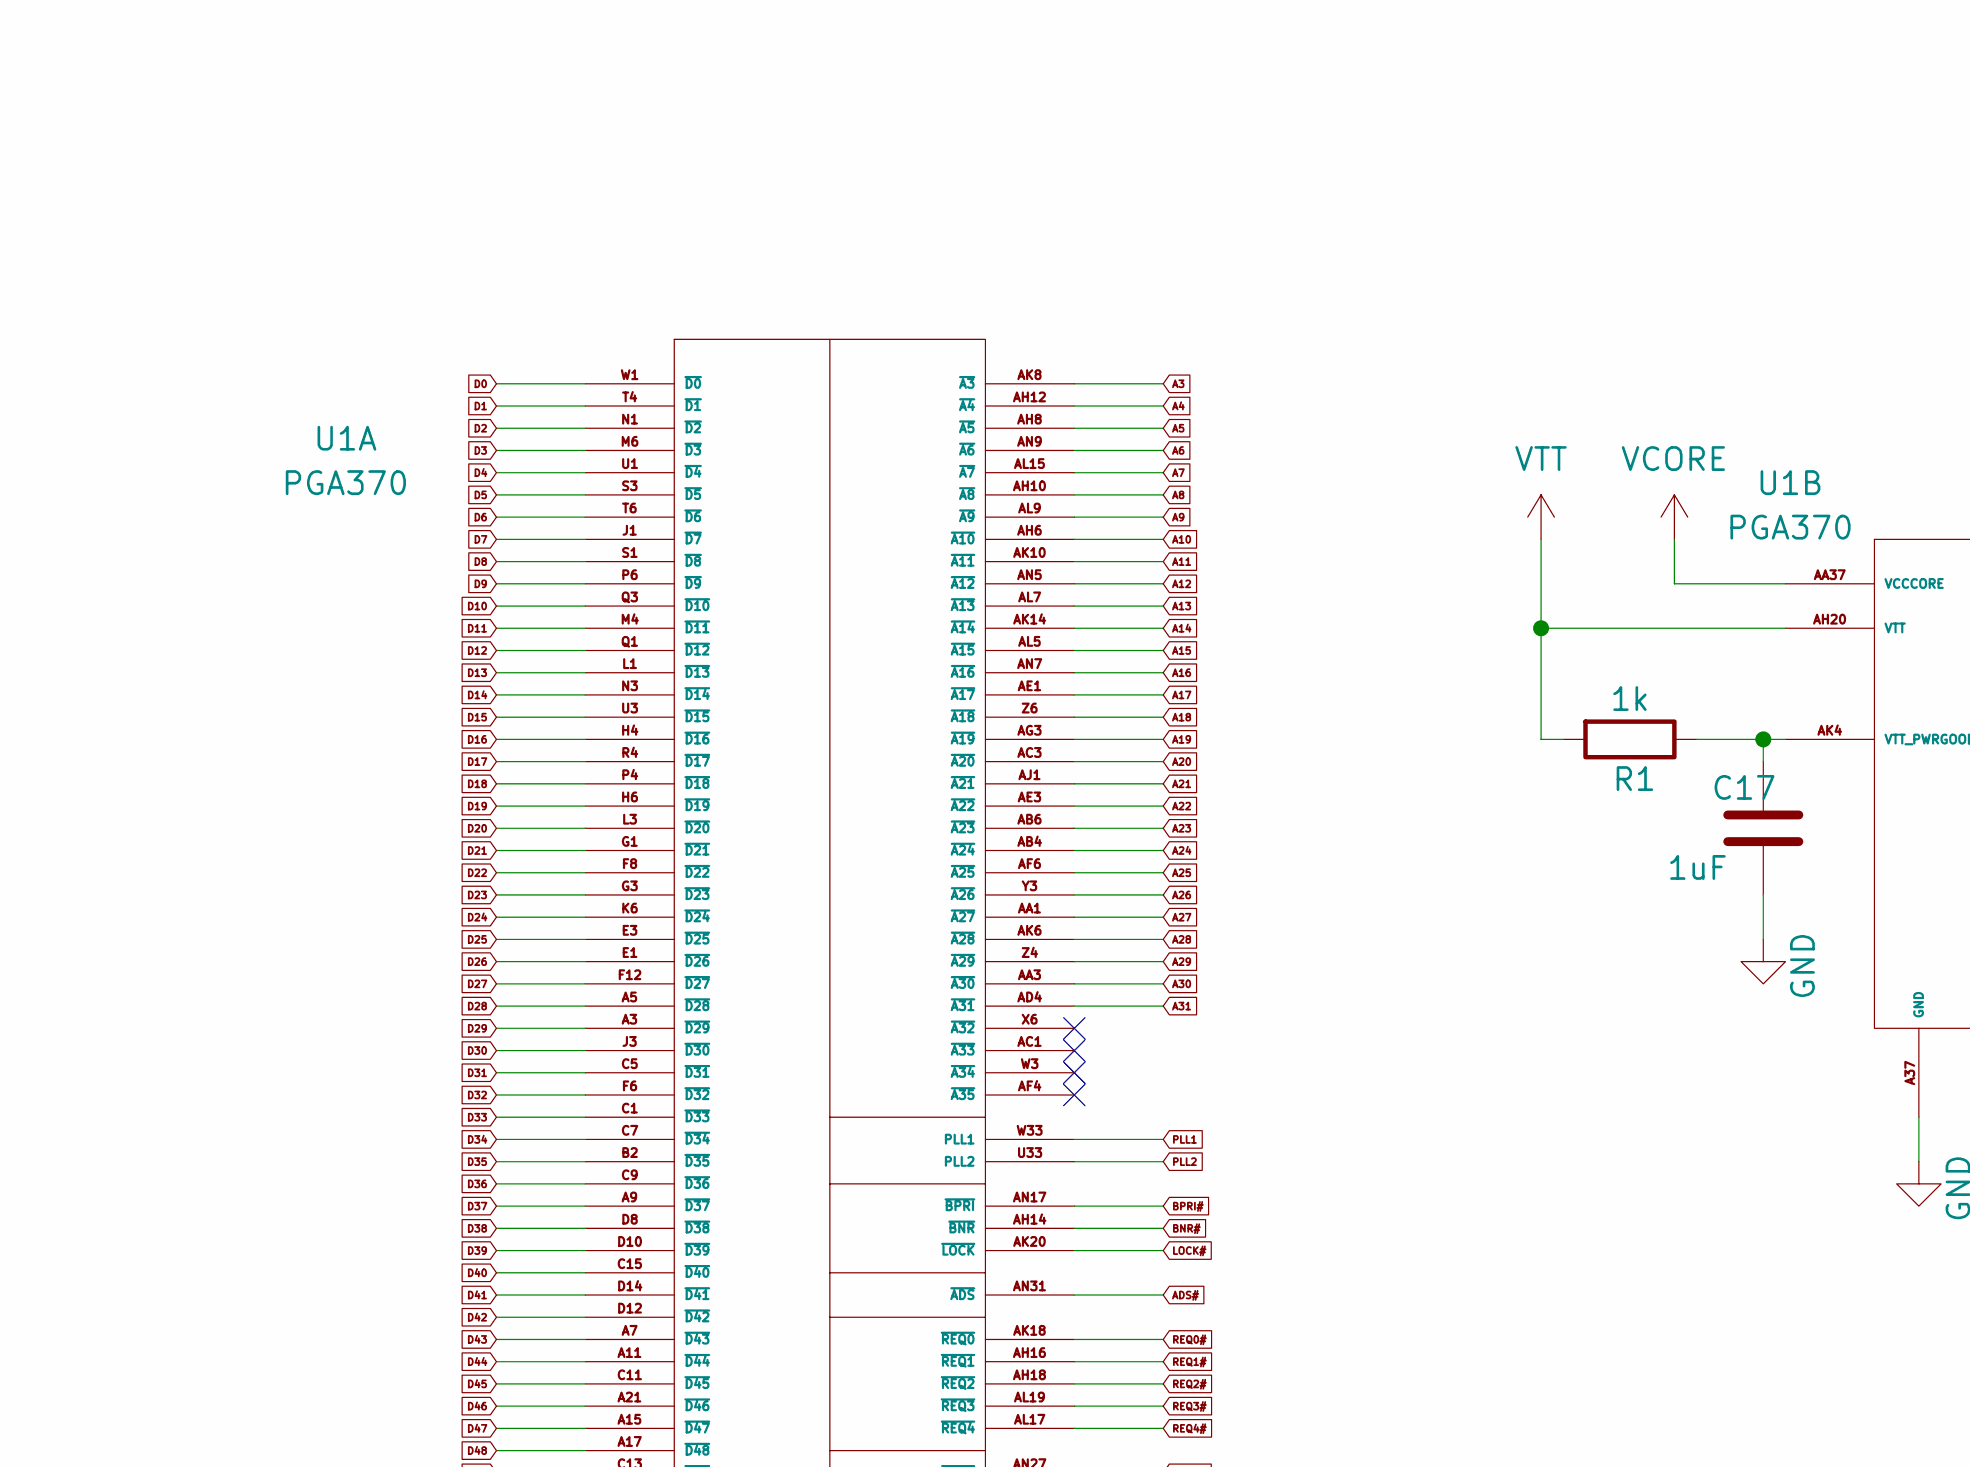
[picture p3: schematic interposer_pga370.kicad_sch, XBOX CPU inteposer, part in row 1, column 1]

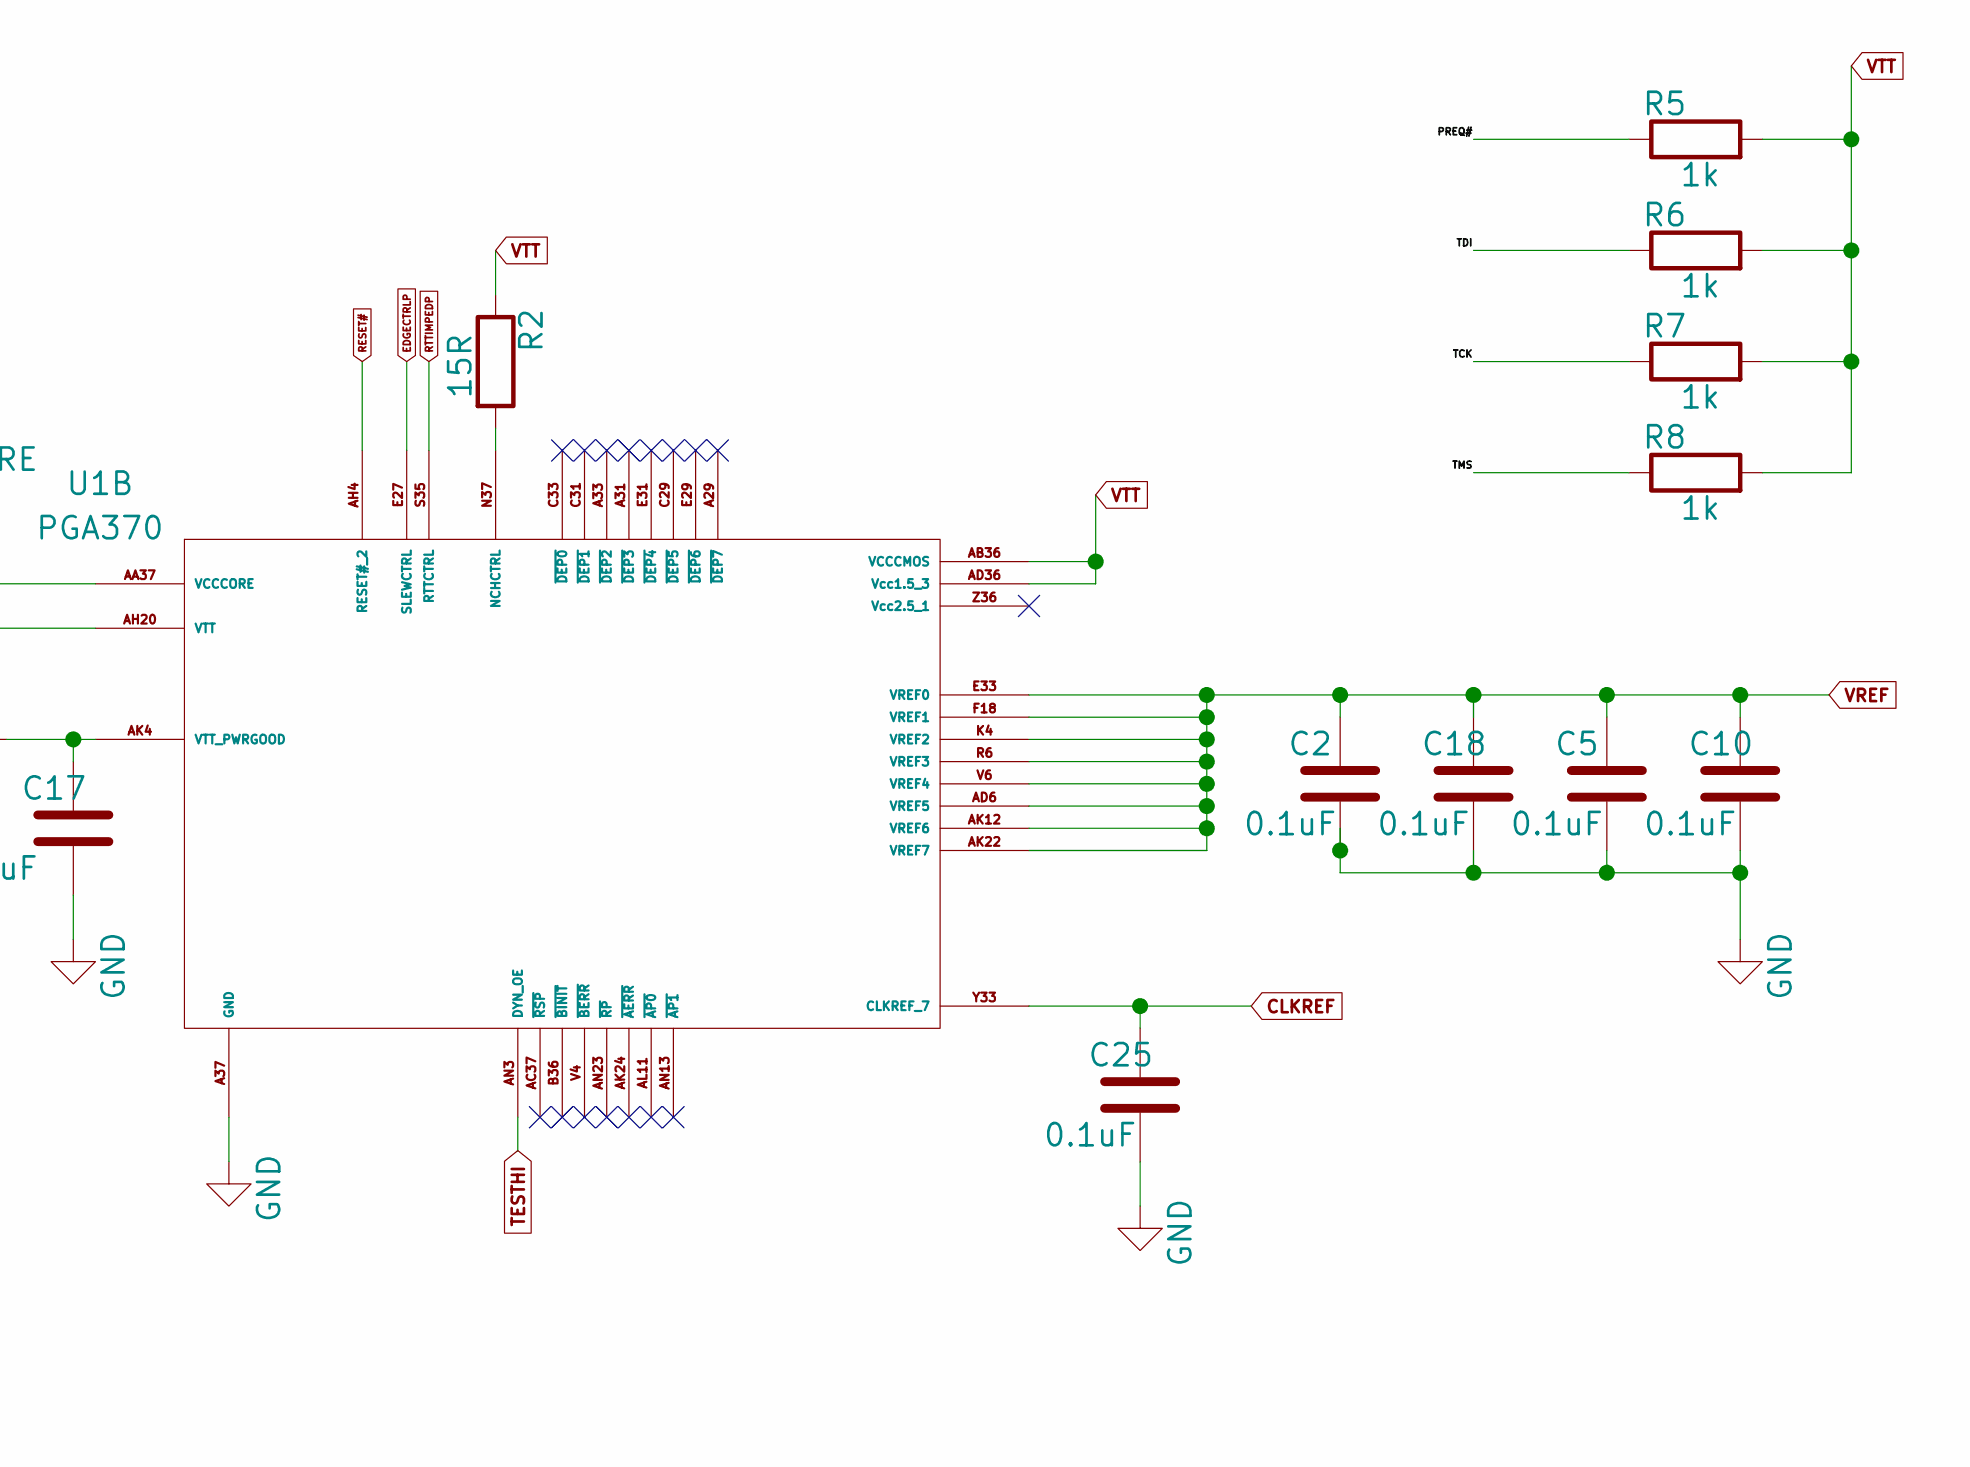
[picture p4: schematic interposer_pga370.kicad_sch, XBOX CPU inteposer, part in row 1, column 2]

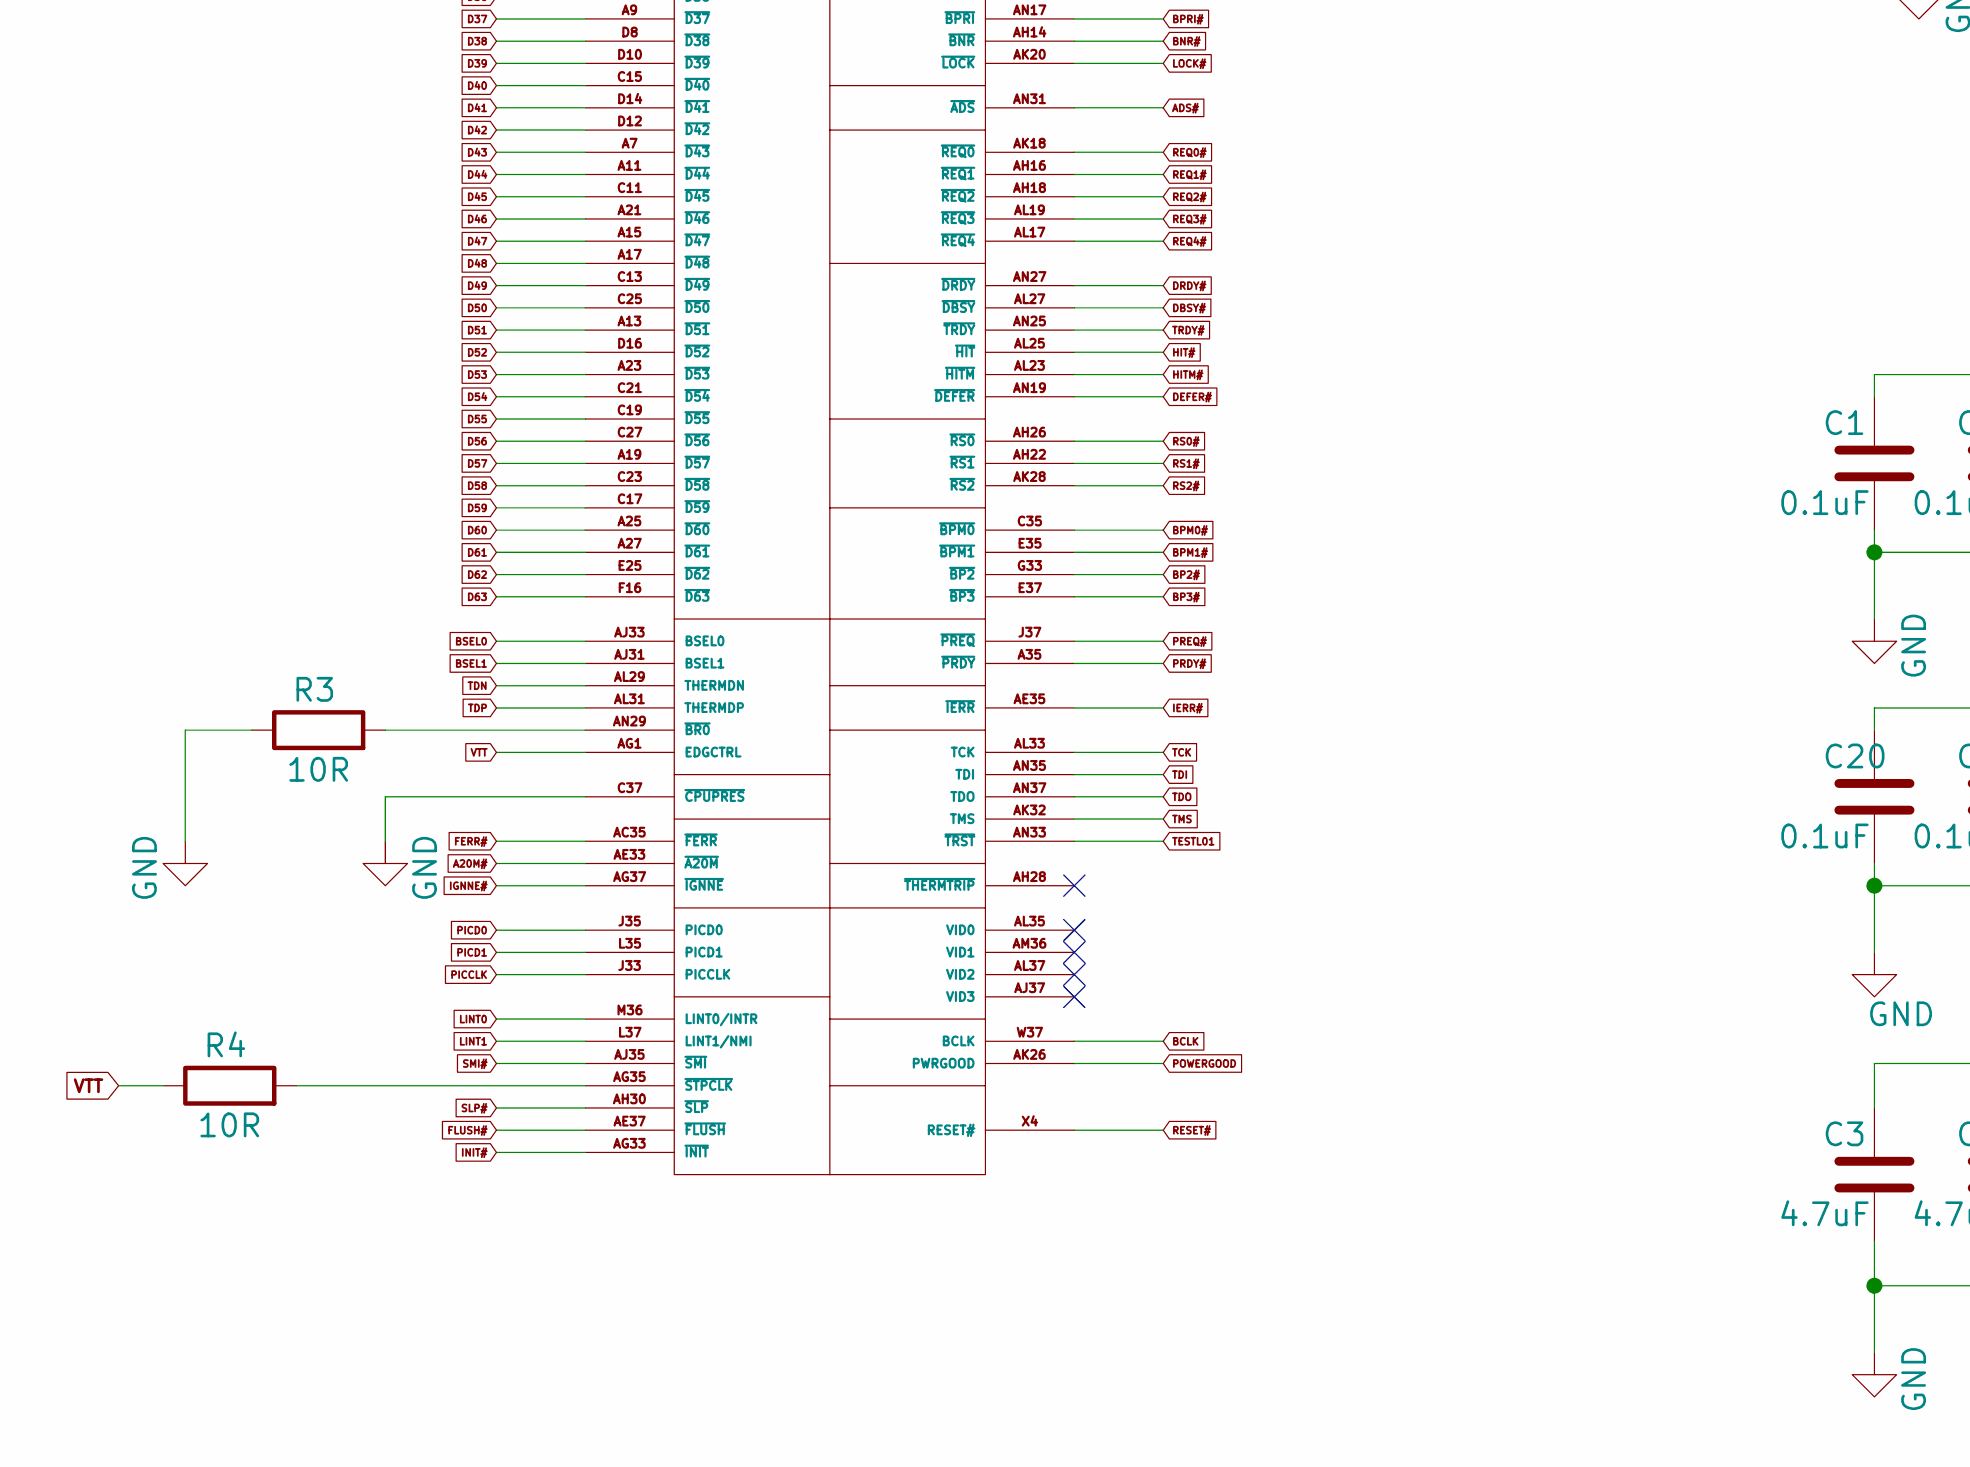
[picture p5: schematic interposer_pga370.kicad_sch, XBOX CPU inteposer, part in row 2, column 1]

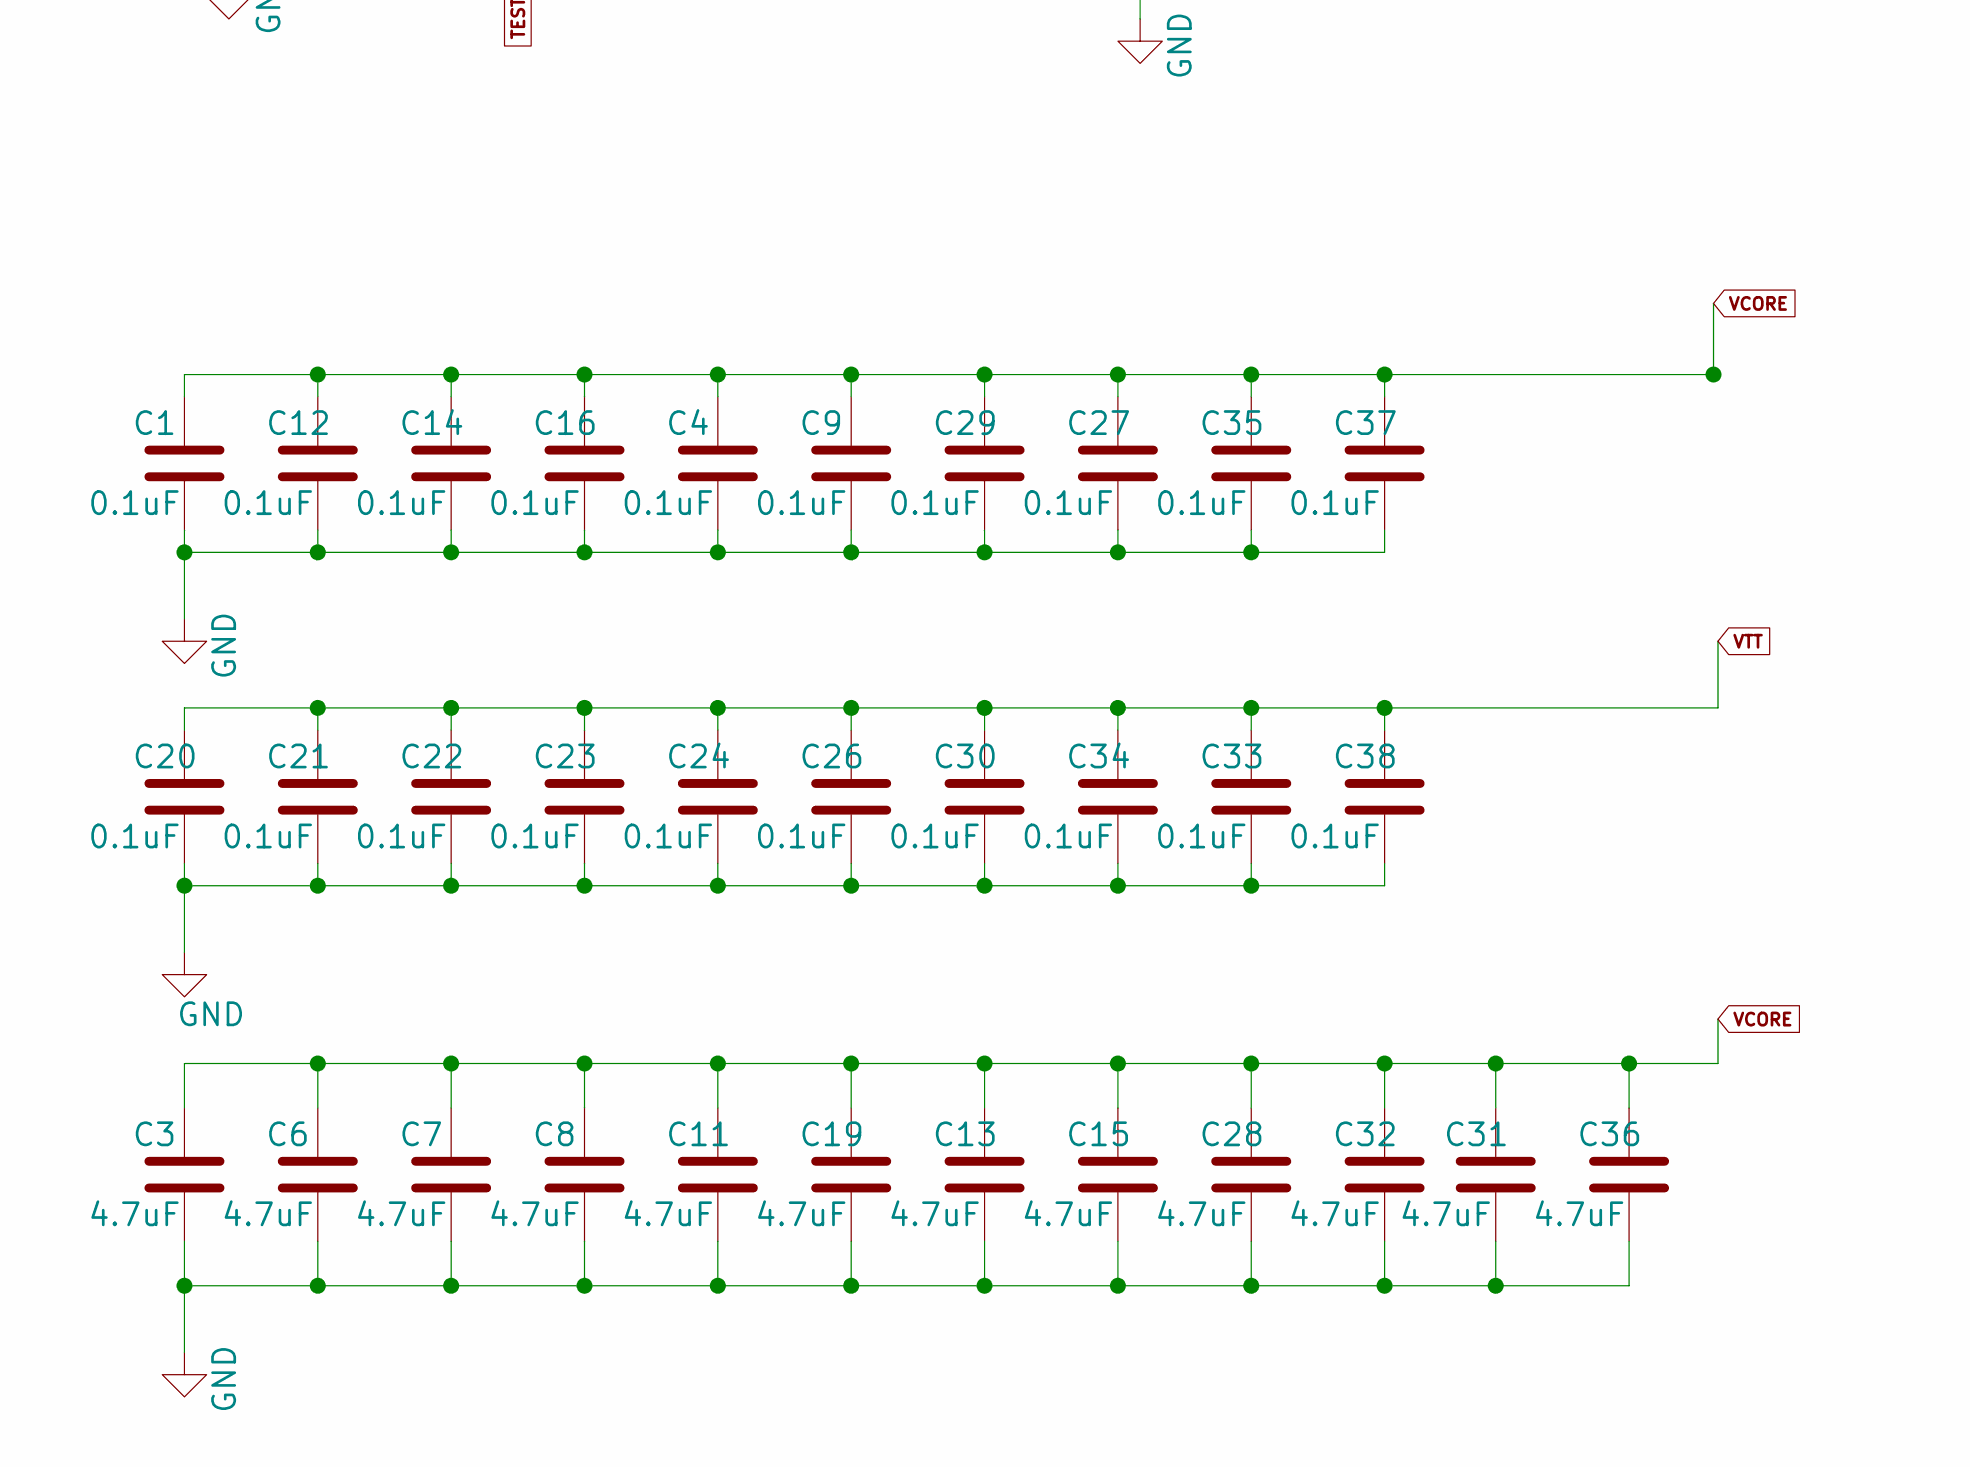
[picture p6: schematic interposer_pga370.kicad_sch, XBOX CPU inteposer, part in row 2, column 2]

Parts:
C1, C2, C4, C5, C9, C10, C12, C14, C16, C18, C20, C21, C22, C23, C24, C25, C26, C27, C29, C30, C33, C34, C35, C37, C38: 0.1uF; C_0603_1608Metric
C3, C6, C7, C8, C11, C13, C15, C19, C28, C31, C32, C36: 4.7uF; C_0805_2012Metric
C17: 1uF; C_0603_1608Metric
R1, R5, R6, R7, R8: 1k; R_0603_1608Metric
R2: 15R; R_0603_1608Metric
R3, R4: 10R; R_0603_1608Metric
U1: PGA370

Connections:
A3: U1.AK8 (~A3); also elsewhere on the board
A4: U1.AH12 (~A4); also elsewhere on the board
A5: U1.AH8 (~A5); also elsewhere on the board
A6: U1.AN9 (~A6); also elsewhere on the board
A7: U1.AL15 (~A7); also elsewhere on the board
A8: U1.AH10 (~A8); also elsewhere on the board
A9: U1.AL9 (~A9); also elsewhere on the board
A10: U1.AH6 (~A10); also elsewhere on the board
A11: U1.AK10 (~A11); also elsewhere on the board
A12: U1.AN5 (~A12); also elsewhere on the board
A13: U1.AL7 (~A13); also elsewhere on the board
A14: U1.AK14 (~A14); also elsewhere on the board
A15: U1.AL5 (~A15); also elsewhere on the board
A16: U1.AN7 (~A16); also elsewhere on the board
A17: U1.AE1 (~A17); also elsewhere on the board
A18: U1.Z6 (~A18); also elsewhere on the board
A19: U1.AG3 (~A19); also elsewhere on the board
A20: U1.AC3 (~A20); also elsewhere on the board
A20M#: U1.AE33 (~A20M); also elsewhere on the board
A21: U1.AJ1 (~A21); also elsewhere on the board
A22: U1.AE3 (~A22); also elsewhere on the board
A23: U1.AB6 (~A23); also elsewhere on the board
A24: U1.AB4 (~A24); also elsewhere on the board
A25: U1.AF6 (~A25); also elsewhere on the board
A26: U1.Y3 (~A26); also elsewhere on the board
A27: U1.AA1 (~A27); also elsewhere on the board
A28: U1.AK6 (~A28); also elsewhere on the board
A29: U1.Z4 (~A29); also elsewhere on the board
A30: U1.AA3 (~A30); also elsewhere on the board
A31: U1.AD4 (~A31); also elsewhere on the board
ADS#: U1.AN31 (~ADS); also elsewhere on the board
BCLK: U1.W37 (BCLK); also elsewhere on the board
BNR#: U1.AH14 (~BNR); also elsewhere on the board
BP2#: U1.G33 (~BP2); also elsewhere on the board
BP3#: U1.E37 (~BP3); also elsewhere on the board
BPM0#: U1.C35 (~BPM0); also elsewhere on the board
BPM1#: U1.E35 (~BPM1); also elsewhere on the board
BPRI#: U1.AN17 (~BPRI); also elsewhere on the board
BSEL0: U1.AJ33 (BSEL0); also elsewhere on the board
BSEL1: U1.AJ31 (BSEL1); also elsewhere on the board
CLKREF: C25.1, U1.Y33 (CLKREF_7); also elsewhere on the board
D0: U1.W1 (~D0); also elsewhere on the board
D1: U1.T4 (~D1); also elsewhere on the board
D2: U1.N1 (~D2); also elsewhere on the board
D3: U1.M6 (~D3); also elsewhere on the board
D4: U1.U1 (~D4); also elsewhere on the board
D5: U1.S3 (~D5); also elsewhere on the board
D6: U1.T6 (~D6); also elsewhere on the board
D7: U1.J1 (~D7); also elsewhere on the board
D8: U1.S1 (~D8); also elsewhere on the board
D9: U1.P6 (~D9); also elsewhere on the board
D10: U1.Q3 (~D10); also elsewhere on the board
D11: U1.M4 (~D11); also elsewhere on the board
D12: U1.Q1 (~D12); also elsewhere on the board
D13: U1.L1 (~D13); also elsewhere on the board
D14: U1.N3 (~D14); also elsewhere on the board
D15: U1.U3 (~D15); also elsewhere on the board
D16: U1.H4 (~D16); also elsewhere on the board
D17: U1.R4 (~D17); also elsewhere on the board
D18: U1.P4 (~D18); also elsewhere on the board
D19: U1.H6 (~D19); also elsewhere on the board
D20: U1.L3 (~D20); also elsewhere on the board
D21: U1.G1 (~D21); also elsewhere on the board
D22: U1.F8 (~D22); also elsewhere on the board
D23: U1.G3 (~D23); also elsewhere on the board
D24: U1.K6 (~D24); also elsewhere on the board
D25: U1.E3 (~D25); also elsewhere on the board
D26: U1.E1 (~D26); also elsewhere on the board
D27: U1.F12 (~D27); also elsewhere on the board
D28: U1.A5 (~D28); also elsewhere on the board
D29: U1.A3 (~D29); also elsewhere on the board
D30: U1.J3 (~D30); also elsewhere on the board
D31: U1.C5 (~D31); also elsewhere on the board
D32: U1.F6 (~D32); also elsewhere on the board
D33: U1.C1 (~D33); also elsewhere on the board
D34: U1.C7 (~D34); also elsewhere on the board
D35: U1.B2 (~D35); also elsewhere on the board
D36: U1.C9 (~D36); also elsewhere on the board
D37: U1.A9 (~D37); also elsewhere on the board
D38: U1.D8 (~D38); also elsewhere on the board
D39: U1.D10 (~D39); also elsewhere on the board
D40: U1.C15 (~D40); also elsewhere on the board
D41: U1.D14 (~D41); also elsewhere on the board
D42: U1.D12 (~D42); also elsewhere on the board
D43: U1.A7 (~D43); also elsewhere on the board
D44: U1.A11 (~D44); also elsewhere on the board
D45: U1.C11 (~D45); also elsewhere on the board
D46: U1.A21 (~D46); also elsewhere on the board
D47: U1.A15 (~D47); also elsewhere on the board
D48: U1.A17 (~D48); also elsewhere on the board
D49: U1.C13 (~D49); also elsewhere on the board
D50: U1.C25 (~D50); also elsewhere on the board
D51: U1.A13 (~D51); also elsewhere on the board
D52: U1.D16 (~D52); also elsewhere on the board
D53: U1.A23 (~D53); also elsewhere on the board
D54: U1.C21 (~D54); also elsewhere on the board
D55: U1.C19 (~D55); also elsewhere on the board
D56: U1.C27 (~D56); also elsewhere on the board
D57: U1.A19 (~D57); also elsewhere on the board
D58: U1.C23 (~D58); also elsewhere on the board
D59: U1.C17 (~D59); also elsewhere on the board
D60: U1.A25 (~D60); also elsewhere on the board
D61: U1.A27 (~D61); also elsewhere on the board
D62: U1.E25 (~D62); also elsewhere on the board
D63: U1.F16 (~D63); also elsewhere on the board
DBSY#: U1.AL27 (~DBSY); also elsewhere on the board
DEFER#: U1.AN19 (~DEFER); also elsewhere on the board
DRDY#: U1.AN27 (~DRDY); also elsewhere on the board
EDGECTRLP: U1.E27 (SLEWCTRL); also elsewhere on the board
FERR#: U1.AC35 (~FERR); also elsewhere on the board
FLUSH#: U1.AE37 (~FLUSH); also elsewhere on the board
GND: C1.2, C2.2, C3.2, C4.2, C5.2, C6.2, C7.2, C8.2, C9.2, C10.2, C11.2, C12.2, C13.2, C14.2, C15.2, C16.2, C17.2, C18.2, C19.2, C20.2, C21.2, C22.2, C23.2, C24.2, C25.2, C26.2, C27.2, C28.2, C29.2, C30.2, C31.2, C32.2, C33.2, C34.2, C35.2, C36.2, C37.2, C38.2, R3.1, U1.A37 (GND), U1.AB32 (GND), U1.AC5 (GND), U1.AC33 (GND), U1.AD2 (GND), U1.AD34 (GND), U1.AF32 (GND), U1.AG5 (GND), U1.AH2 (GND), U1.AH34 (GND), U1.AJ7 (GND), U1.AJ11 (GND), U1.AJ15 (GND), U1.AJ19 (GND), U1.AJ23 (GND), U1.AJ27 (GND), U1.AL3 (GND), U1.AM6 (GND), U1.AM10 (GND), U1.AM14 (GND), U1.AM18 (GND), U1.AM22 (GND), U1.AM26 (GND), U1.AM30 (GND), U1.AM34 (GND), U1.B4 (GND), U1.B8 (GND), U1.B12 (GND), U1.B16 (GND), U1.B20 (GND), U1.B24 (GND), U1.B28 (GND), U1.B32 (GND), U1.C37 (~CPUPRES), U1.D2 (GND), U1.D4 (GND), U1.D18 (GND), U1.D22 (GND), U1.D26 (GND), U1.D30 (GND), U1.D34 (GND), U1.E7 (GND), U1.E11 (GND), U1.E15 (GND), U1.E19 (GND), U1.F20 (GND), U1.F24 (GND), U1.F28 (GND), U1.F32 (GND), U1.F36 (GND), U1.G5 (GND), U1.H2 (GND), U1.H34 (GND), U1.K36 (GND), U1.L5 (GND), U1.M2 (GND), U1.M34 (GND), U1.P32 (GND), U1.P36 (GND), U1.Q5 (GND), U1.R34 (GND), U1.T32 (GND), U1.T36 (GND), U1.U5 (GND), U1.V2 (GND), U1.V34 (GND), U1.X32 (GND), U1.X36 (GND), U1.Y5 (GND), U1.Y37 (GND), U1.Z2 (GND), U1.Z34 (GND); also elsewhere on the board
HIT#: U1.AL25 (~HIT); also elsewhere on the board
HITM#: U1.AL23 (~HITM); also elsewhere on the board
IERR#: U1.AE35 (~IERR); also elsewhere on the board
IGNNE#: U1.AG37 (~IGNNE); also elsewhere on the board
INIT#: U1.AG33 (~INIT); also elsewhere on the board
LINT0: U1.M36 (LINT0/INTR); also elsewhere on the board
LINT1: U1.L37 (LINT1/NMI); also elsewhere on the board
LOCK#: U1.AK20 (~LOCK); also elsewhere on the board
unnamed: R3.2, U1.AN29 (~BR0)
unnamed: R4.2, U1.AG35 (~STPCLK)
unnamed: R2.2, U1.N37 (NCHCTRL)
unnamed: C17.1, R1.1, U1.AK4 (VTT_PWRGOOD)
PICCLK: U1.J33 (PICCLK); also elsewhere on the board
PICD0: U1.J35 (PICD0); also elsewhere on the board
PICD1: U1.L35 (PICD1); also elsewhere on the board
PLL1: U1.W33 (PLL1); also elsewhere on the board
PLL2: U1.U33 (PLL2); also elsewhere on the board
POWERGOOD: U1.AK26 (PWRGOOD); also elsewhere on the board
PRDY#: U1.A35 (~PRDY); also elsewhere on the board
PREQ#: R5.1, U1.J37 (~PREQ)
REQ0#: U1.AK18 (~REQ0); also elsewhere on the board
REQ1#: U1.AH16 (~REQ1); also elsewhere on the board
REQ2#: U1.AH18 (~REQ2); also elsewhere on the board
REQ3#: U1.AL19 (~REQ3); also elsewhere on the board
REQ4#: U1.AL17 (~REQ4); also elsewhere on the board
RESET#: U1.AH4 (RESET#_2), U1.X4 (RESET#); also elsewhere on the board
RS0#: U1.AH26 (~RS0); also elsewhere on the board
RS1#: U1.AH22 (~RS1); also elsewhere on the board
RS2#: U1.AK28 (~RS2); also elsewhere on the board
RTTIMPEDP: U1.S35 (RTTCTRL); also elsewhere on the board
SLP#: U1.AH30 (~SLP); also elsewhere on the board
SMI#: U1.AJ35 (~SMI); also elsewhere on the board
TCK: R7.1, U1.AL33 (TCK)
TDI: R6.1, U1.AN35 (TDI)
TDN: U1.AL29 (THERMDN); also elsewhere on the board
TDO: U1.AN37 (TDO); also elsewhere on the board
TDP: U1.AL31 (THERMDP); also elsewhere on the board
TESTHI: U1.AN3 (DYN_OE); also elsewhere on the board
TESTL01: U1.AN33 (~TRST); also elsewhere on the board
TMS: R8.1, U1.AK32 (TMS)
TRDY#: U1.AN25 (~TRDY); also elsewhere on the board
VCORE: C1.1, C3.1, C4.1, C6.1, C7.1, C8.1, C9.1, C11.1, C12.1, C13.1, C14.1, C15.1, C16.1, C19.1, C27.1, C28.1, C29.1, C31.1, C32.1, C35.1, C36.1, C37.1, U1.AA5 (VCORE), U1.AA37 (VCCCORE), U1.AB2 (VCORE), U1.AB34 (VCORE), U1.AD32 (VCORE), U1.AE5 (VCORE), U1.AF2 (VCORE), U1.AF34 (VCORE), U1.AH24 (VCORE), U1.AH32 (VCORE), U1.AH36 (VCORE), U1.AJ5 (VCORE), U1.AJ9 (VCORE), U1.AJ13 (VCORE), U1.AJ17 (VCORE), U1.AJ21 (VCORE), U1.AJ25 (VCORE), U1.AJ29 (VCORE), U1.AK2 (VCORE), U1.AK34 (VCORE), U1.AM4 (VCORE), U1.AM8 (VCORE), U1.AM12 (VCORE), U1.AM16 (VCORE), U1.AM20 (VCORE), U1.AM24 (VCORE), U1.AM28 (VCORE), U1.AM32 (VCORE), U1.B6 (VCORE), U1.B10 (VCORE), U1.B14 (VCORE), U1.B18 (VCORE), U1.B22 (VCORE), U1.B26 (VCORE), U1.B30 (VCORE), U1.B34 (VCORE), U1.C3 (VCORE), U1.D6 (VCORE), U1.D20 (VCORE), U1.D24 (VCORE), U1.D28 (VCORE), U1.D32 (VCORE), U1.D36 (VCORE), U1.E5 (VCORE), U1.E9 (VCORE), U1.E13 (VCORE), U1.E17 (VCORE), U1.F2 (VCORE), U1.F4 (VCORE), U1.F14 (VCORE), U1.F22 (VCORE), U1.F26 (VCORE), U1.F30 (VCORE), U1.F34 (VCORE), U1.H32 (VCORE), U1.H36 (VCORE), U1.J5 (VCORE), U1.K2 (VCORE), U1.K32 (VCORE), U1.K34 (VCORE), U1.M32 (VCORE), U1.N5 (VCORE), U1.P2 (VCORE), U1.P34 (VCORE), U1.R32 (VCORE), U1.R36 (VCORE), U1.S5 (VCORE), U1.T2 (VCORE), U1.T34 (VCORE), U1.V32 (VCORE), U1.V36 (VCORE), U1.W5 (VCORE), U1.Y35 (VCORE), U1.Z32 (VCORE); also elsewhere on the board
VREF: C2.1, C5.1, C10.1, C18.1, U1.AD6 (VREF5), U1.AK12 (VREF6), U1.AK22 (VREF7), U1.E33 (VREF0), U1.F18 (VREF1), U1.K4 (VREF2), U1.R6 (VREF3), U1.V6 (VREF4); also elsewhere on the board
VTT: C20.1, C21.1, C22.1, C23.1, C24.1, C26.1, C30.1, C33.1, C34.1, C38.1, R1.2, R2.1, R4.1, R5.2, R6.2, R7.2, R8.2, U1.AA33 (VTT), U1.AA35 (VTT), U1.AB36 (VCCCMOS), U1.AD36 (Vcc1.5_3), U1.AG1 (EDGCTRL), U1.AH20 (VTT), U1.AK16 (VTT), U1.AL13 (VTT), U1.AL21 (VTT), U1.AN11 (VTT), U1.AN15 (VTT), U1.AN21 (VTT), U1.E23 (VTT), U1.G35 (VTT), U1.G37 (VTT), U1.S33 (VTT), U1.S37 (VTT), U1.U35 (VTT), U1.U37 (VTT), U1.X34 (VTT); also elsewhere on the board

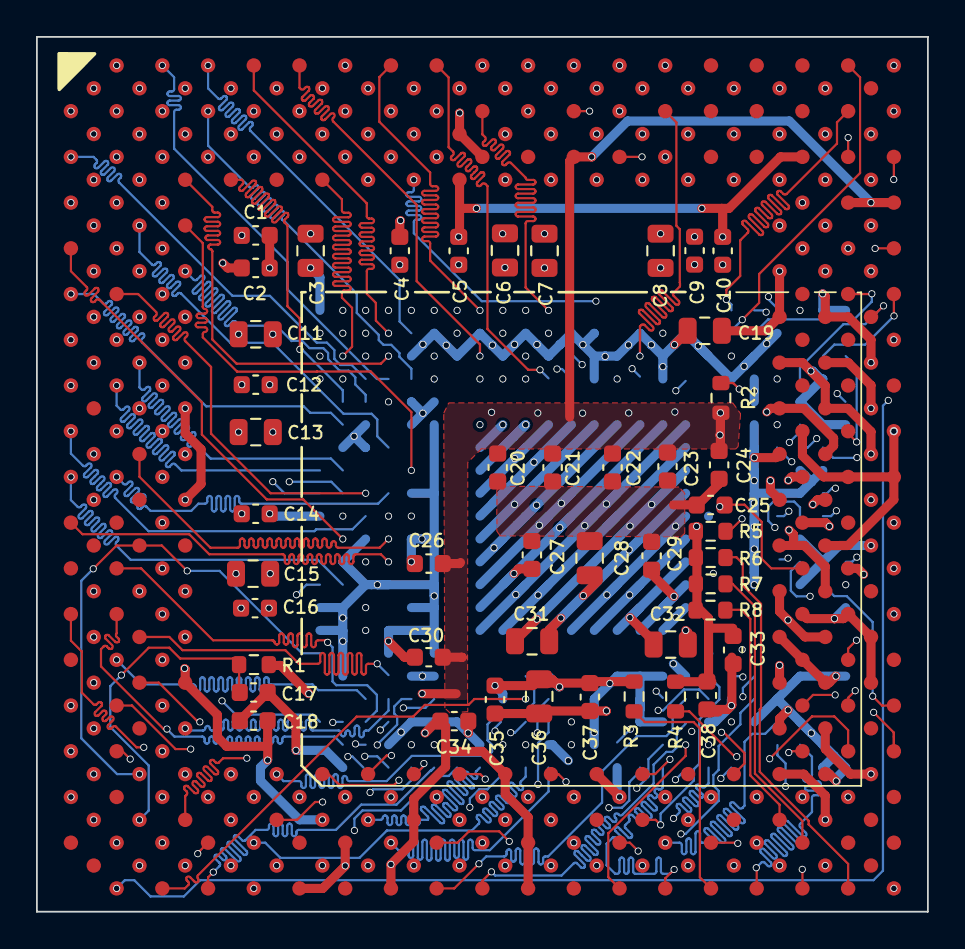
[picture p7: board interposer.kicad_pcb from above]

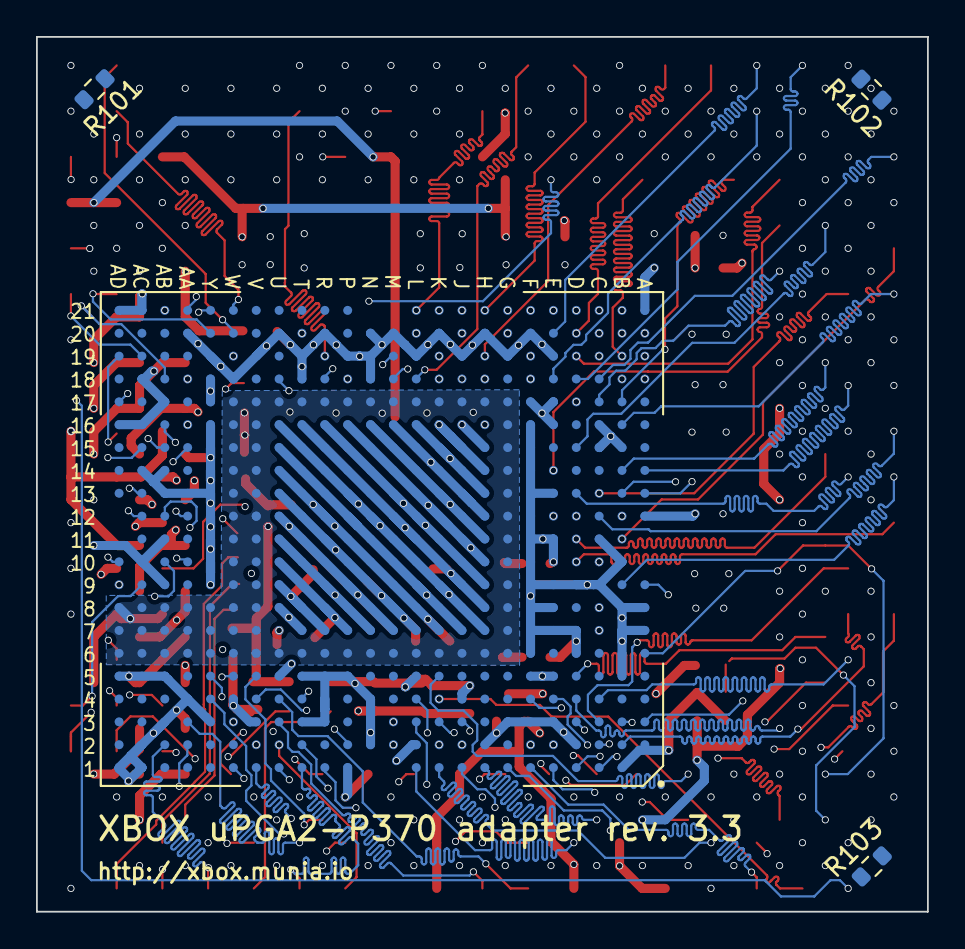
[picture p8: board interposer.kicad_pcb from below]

Board: 6 copper layers, 49.5 x 48.6 mm, 51 parts (4 on the bottom side), 156 nets.

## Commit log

2023-11-26 Add aligned and cleaned-up scans of delayered board
2023-11-26 Add kicad project with sch, symbols, footprints and pcb
    [interposer.kicad_sch, interposer_pga370.kicad_sch, xbox_ubga2.kicad_sch]
2023-11-28 Reroute with BGA more centered and cheaper design fabrications (0.3mm drills).
    [interposer_pga370.kicad_sch]
2023-11-29 Optimizations: - remove via's out of silk screen text - eliminate warnings - tighter board outline
    [interposer.kicad_pcb]
2023-12-01 Add tool to help with alignment of the board
    [interposer-aligntool.kicad_pcb]
2023-12-01 Add gerbers for aligntool
2023-12-01 Revision 3; much cleaner layout with traces tuned to 25mm.
    [interposer.kicad_pcb, interposer_pga370.kicad_sch]
2023-12-08 Rev 3.1: - change via's to 0.3mm drill/0.4mm ring for cheaper manufacturing - add leveling 0603 resistors on backside in the corners to prevent PCB tilt during reflow
    [interposer.kicad_pcb, xbox_ubga2.kicad_sch]
2024-01-07 Revision 3.2
    Implement fixes that allow interposer to be actually functional for the first time:
    - Fix uBGA495 pin P1 from VTT --> VCC since this is VCC on xbox motherboard.
    - Fix P370 pin AJ3 (RESET2#) from GND --> NC.
    Furthermore, pins AL1 (reserved), AK36 (VID output), AF36 (DETECT) now left NC instead of connected to GND.
    Outline slightly trimmed near bottom to provide some clearance against a cap on 1.6 motherboards.
    Design specs loosened, from 4 mil tracks/4 mil clearance/0.3mm drills --> 5 mil/5 mil/0.3mm.
    Board thickness recommendation is now 1.6mm instead of 1.2mm for additional rigidity.
    Trace lengths now matched at 27.0mm (was 25.0mm).
    Added BGA footprint indicator on front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
    [interposer-aligntool.kicad_pcb, interposer.kicad_pcb, interposer_pga370.kicad_sch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]
2024-01-07 Update BOM
2024-08-14 Rev. 3.3, minor changes: - Resistor network RN01 changed to 4 distinct 0603's since people continuously order an incorrect part - Height of interposer slightly reduced by 0.3mm on both top and bottom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
    [interposer-aligntool.kicad_pcb, interposer.kicad_pcb, interposer.kicad_sch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]
